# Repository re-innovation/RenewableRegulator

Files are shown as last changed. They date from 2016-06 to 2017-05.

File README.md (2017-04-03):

# Renewable Regulator

# Overview

This is an open-source project to design a simple, low-cost, Charge Regulator Designs for off-grid renewable energy projects.

A charge-controller protects a re-chargeable battery from over (and sometime under) charging from a renewable energy resource.

This controller will work as a Series and Shunt controller. Future improvements include working as a Maximum Power Point Tracking.
The design is based upon the Arduino IDE and will use one version of the Arduino processors (Arduino Nano initially).
Voltage is measured using a potential divider.
Current is measured using a hall-effect current sensor.
Temperature is measured using a 1-wire digital temperature probe.

A small OLED or LCD screen is used to show the data.
A rotary encoder is used for input data.
Data will also be sent via a serial connection for data-logging use.

## Specifications:

Maximum working voltage: 60V DC
Maximum working current: 50A DC
Measurement accuracy voltage:
Measurement accuracy current:
Temperature: -20 to 150C 0.1C steps

## Contributors

Overview and project concept by Matthew Little (matt@re-innovation.co.uk)
Phase 1 by Arnaud Moulas (arnaud.moulas@gmail.com)
Phase 2 by Yoan Gornes (yoan.gornes@gmail.com)

This project has been part of a larger project for modular power electronics concept initiated by Wind Empowerment:
http://www.wisions.net/projects/exchange-modular-power-to-the-people-democratising-energy-access-through-mo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

This section of the project is designed to stand-alone as a charge controller, but the code will be incorporated into the larger project.

# Series Regulator

A series charge controller or series regulator disables further current flow into batteries when they are full.

# Shunt Regulator

A shunt charge controller or shunt regulator diverts excess electricity to an auxiliary or "shunt" load, such as an electric water heater, when batteries are full.

# MPPT Algorithm

At present this function is not included. In the future a DC-DC converter can be used to separately

# Battery types

A rechargeable battery, storage battery, secondary cell, or accumulator is a type of electrical battery which can be charged, discharged into a load, and recharged many times, while a non-rechargeable or primary battery is supplied fully charged, and discarded once discharged. It is composed of one or more electrochemical cells. The term "accumulator" is used as it accumulates and stores energy through a reversible electrochemical reaction. Rechargeable batteries are produced in many different shapes and sizes, ranging from button cells to megawatt systems connected to stabilize an electrical distribution network.
Several different combinations of electrode materials and electrolytes are used, including lead–acid, nickel cadmium (NiCd), nickel metal hydride (NiMH), lithium ion (Li-ion), and lithium ion polymer (Li-ion polymer).

# Data Protocol

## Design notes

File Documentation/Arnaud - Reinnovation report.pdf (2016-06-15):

# CHARGE CONTROLLERS : SERIES, SHUNT, MPPT

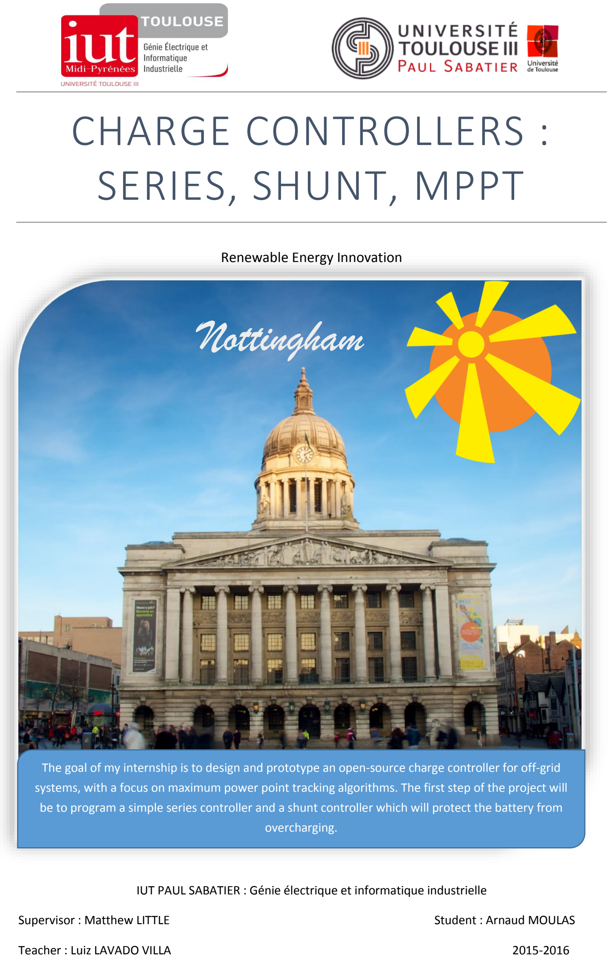
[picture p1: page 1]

Renewable Energy Innovation

# Nottingham

IUT PAUL SABATIER : Génie électrique et informatique industrielle

Supervisor : Matthew LITTLE | Student : Arnaud MOULAS
Teacher : Luiz LAVADO VILLA | 2015-2016

The goal of my internship is to design and prototype an open-source charge controller for off-grid systems, with a focus on maximum power point tracking algorithms. The first step of the project will be to program a simple series controller and a shunt controller which will protect the battery from overcharging.

Acknowledgement

2 | P a g e
Acknowledgement

# Acknowledgement

I would like to thanks :

- Lythisha who welcomed me to her house during the internship. She was really nice and she has a a cosy nice house near a supermarket and the tram. It allowed me to buy food for a cheap price and easily go to work thanks to the tram.
- Luiz Lavado Villa to put me in contact with Matthew little from the company Re-innovation.co.uk. Luiz was very active and really helpful. He organized meetings every weeks before the internship to prepare us. It permitted me to understand a bit prior to the internship the work I would have to do.
- Matthew Little who is my supervisor. He was attentive to me so it was a pleasure to work with him. He taught me a lot about how to lead a project from scratch. I am always surprised when I have a problem that Matthew can find the solution quickly.

Synopsis

Synopsis

# Synopsis :

Presentation of the company : | 4-5

Presentation of the company

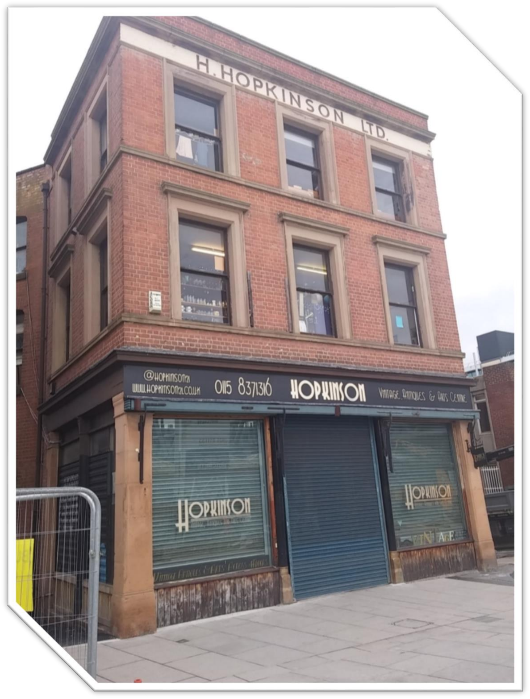
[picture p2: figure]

Presentation of the company

# Presentation of the company :

Re-innovation is a small business company created by Matthew little. It is mainly accessible for the customer through the website www.re-innovation.co.uk

Matthew’s workshop is at the second floor

Presentation of the company

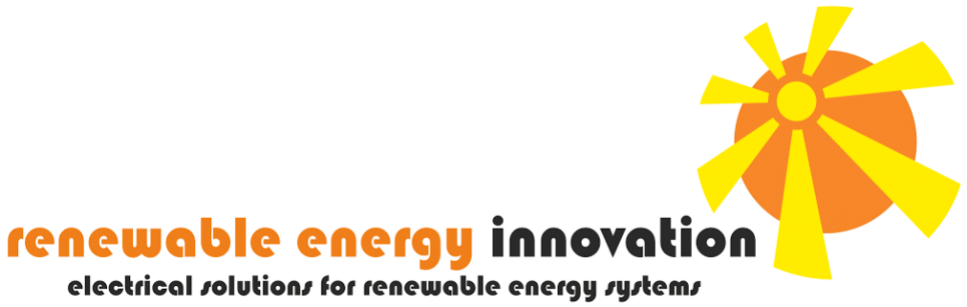
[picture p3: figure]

Presentation of the company

“Renewable Energy Innovation specialize in electrical and electronic systems for renewable energy projects, mainly solar, wind and micro-hydro. We focus on renewable energy based stand-alone power supply systems (off-grid systems). This includes power and energy monitoring, battery charge control and wiring systems. Projects we have been involved with range from small, portable solar-powered systems, through pedal powered devices up to large multi-kilowatt photovoltaic arrays. The projects, information and blog pages contain details of some of the projects we have worked on. We also design, build and test bespoke pieces of renewable energy equipment.” ~Matthew Little

I worked at the Hopkinson gallery which is a vintage shop and a coffee at the same time. Matthew’s workshop is on the second floor. I had a desk with all the equipment needed to program the arduino uno and test the algorithm. Matthew’s desk is in the next room so it is easy for me to communicate with him.

I have been working in really great condition.

Logo of the company

Introduction

Introduction

# Introduction :

I am a French student studying computer science. In order to get my degree I need to participate to an internship. Matthew Little responded positively to my mail and I am now happy to spend my internship in Nottingham for the company Re-innovation.co.uk. The plan for me was to design and test different charge controller’s algorithm on an arduino uno.

Initially the project was decomposed in 3 big parts :

Series controller :

1) Algorithm
2) Program on arduino
3) Test on the prototype

Shunt controller

1) Algorithm
2) Program on arduino
3) Test prototype

Maximum Power Point Tracking (MPPT) :

1) Algorithm
2) Program it on arduino
3) Test the prototype

However in practice the first 2 steps were merged as their functioning was similar.

Introduction

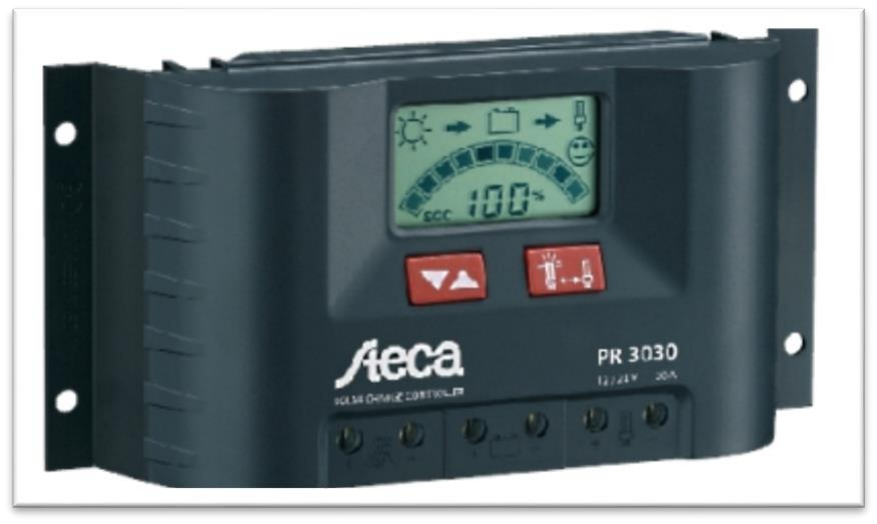
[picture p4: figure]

Introduction : Project

## Project :

The goal of my internship is to design and prototype an open-source charge controller for off-grid systems, with a focus on maximum power point tracking algorithms.

The first step of the project will be to program a simple series controller and a shunt controller which will protect the battery from overcharging.

Series controller : A series charge controller or series regulator disables further current flow into batteries when they are full.

Shunt controller : A shunt charge controller or shunt regulator diverts excess electricity to an auxiliary or "shunt" load, such as an electric water heater, when batteries are full

Before working Matthew explained me the project and detailed me each steps. He draw simple graphics it permit me to understand how is working the series controller from an electrical point of view.

Exemple of solar panel controller found in shops

Introduction

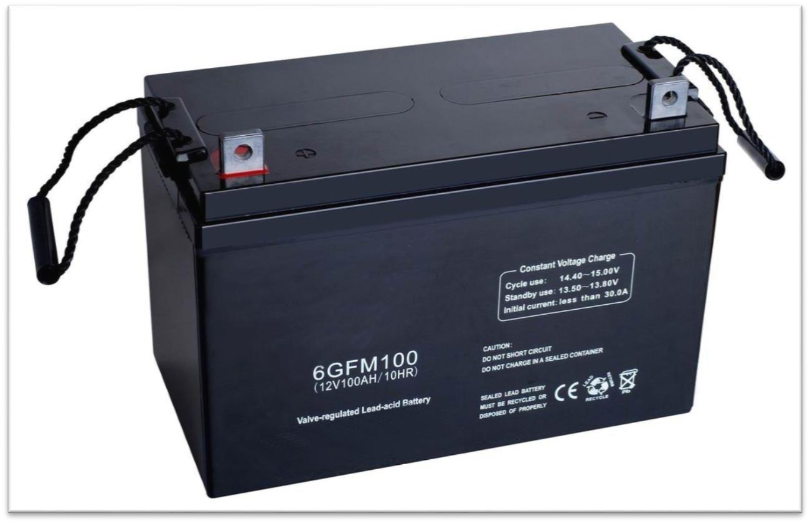
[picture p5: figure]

Introduction : What is a rechargeable battery ?

## What is a rechargeable battery :

A rechargeable battery, storage battery, secondary cell, or accumulator is a type of electrical battery which can be charged, discharged into a load, and recharged many times, while a non-rechargeable or primary battery is supplied fully charged, and discarded once discharged. It is composed of one or more electrochemical cells. The term "accumulator" is used as it accumulates and stores energy through a reversible electrochemical reaction. Rechargeable batteries are produced in many different shapes and sizes, ranging from button cells to megawatt systems connected to stabilize an electrical distribution network.

Several different combinations of electrode materials and electrolytes are used, including lead– acid, nickel cadmium (NiCd), nickel metal hydride (NiMH), lithium ion (Li-ion), and lithium ion polymer (Li-ion polymer). Rechargeable batteries initially cost more than disposable batteries, but have a much lower total cost of ownership and environmental impact, as they can be recharged inexpensively many times before they need replacing. Some rechargeable battery types are available in the same sizes and voltages as disposable types, and can be used interchangeably with them.

Usually the battery used with off grid energy are big and heavy

Introduction

Introduction : What are the cause of damage to a battery ?

## What are the cause of damage to a battery ?

## Damage from cell reversal

Subjecting a discharged cell to a current in the direction which tends to discharge it further to the point the positive and negative terminals switch polarity causes a condition called cell reversal. Generally, pushing current through a discharged cell in this way causes undesirable and irreversible chemical reactions to occur, resulting in permanent damage to the cell. Cell reversal can occur under a number of circumstances, the two most common being:

- When a battery or cell is connected to a charging circuit the wrong way around.
- When a battery made of several cells connected in series is deeply discharged.

In the latter case, the problem occurs due to the different cells in a battery having slightly different capacities. When one cell reaches discharge level ahead of the rest, the remaining cells will force the current through the discharged cell.

Many battery-operated devices have a low-voltage cutoff that prevents deep discharges from occurring that might cause cell reversal.

## Damage from overcharging

During the final stages of charging, all lead-acid batteries break down some of the electrolyte in a battery into hydrogen and oxygen. With sealed batteries, such as gel cells and AGMs, the gases are normally contained within the battery, although in certain circumstances (notably, persistent overcharging), enough internal pressure can build up to open pressure release valves and vent the gases. With wet cell batteries – the type that need topping up from time to time – the gases are always vented.

Hydrogen, which is highly explosive, is much lighter than air, so typically will rapidly rise and disperse, so long as there is even minimal venting from the top of a battery box and from the top of the compartment in which the battery box is housed. However, if a pocket of gas forms, any spark (such as from a brushed electric motor kicking on) may set off the hydrogen, on occasion resulting in a powerful explosion. This is what blew the top off the Fukushima nuclear power plants in Japan. Occasionally, internal short circuits create a spark inside batteries that can set off a hydrogen explosion within the battery, blowing the case open. Note that this can occur with sealed batteries as well as with wet cell batteries.

When batteries are worked hard, they generate a fair amount of internal heat. This increases a battery’s ability to absorb charging current without its voltage rising, which effectively disables any voltage regulator on the charging device, resulting in gross overcharging. The battery can get into a condition known as ‘thermal runaway’ in which it soaks up all the charging current that can be thrown at it, converting this into hydrogen, oxygen and heat – a dangerously potent mix. The only effective way to guard against this is to have temperature sensing at the battery, linked to the charging device.

Introduction

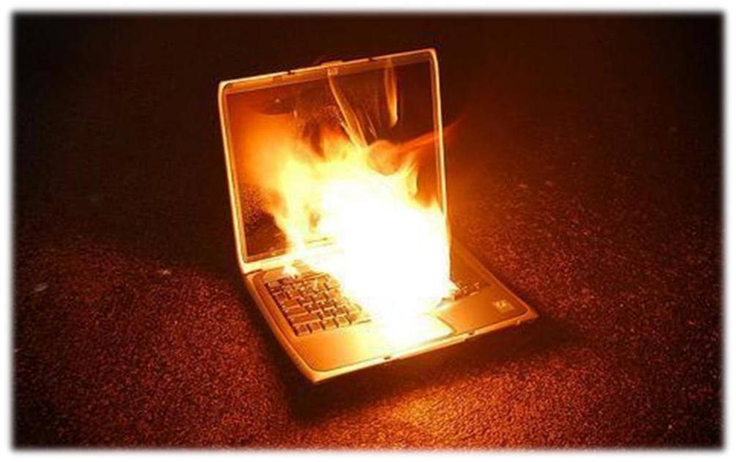
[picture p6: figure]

Introduction : What are the cause of damage to a battery ?

## Damage from over dis-charging

If a cell's voltage reaches a designed value, that means the battery has discharged the stored capacity, but still the discharge action is continual, over-discharge will cause. Commonly the end voltage can be identified through discharge current, for example the end voltage is set at 1.0V/cell as discharged at 0.2C-2C, and 0.8V/cell at 3C or more, e.g. 5C or 10C. Over discharge may cause disaster, especially at heavy current or repeated over discharge. Commonly over discharge can make cell inner pressure raise, and the reversibility of activity materials both in positive and negative will be damaged. Even by charge only part can recover and the capacity is reduced obviously.

A laptop’s battery can burn if too much damaged

Introduction

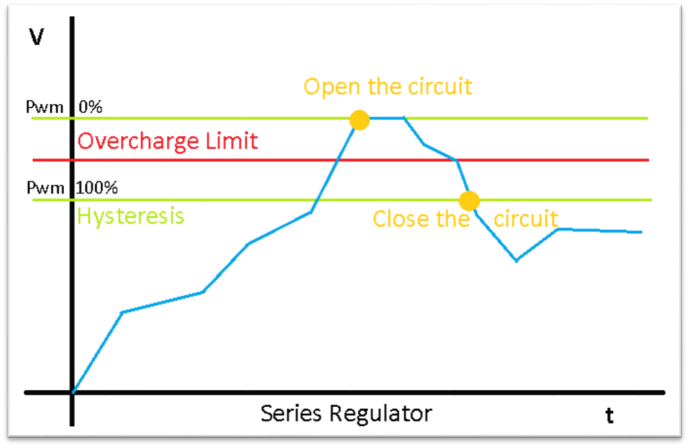
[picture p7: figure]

Introduction : Different type of charge controllers

## Different type of charge controllers :

## Series controller :

Electric scheme for serie controller

The series controller works by providing a path from the supply voltage to the load through a variable resistance (the main transistor is in the "top half" of the voltage divider). The power dissipated by the regulating device is equal to the power supply output current times the voltage drop in the regulating device.

Series controller can only be used for current limited power sources (such as solar panels).

Illustration of the behavior of Series controller

Introduction

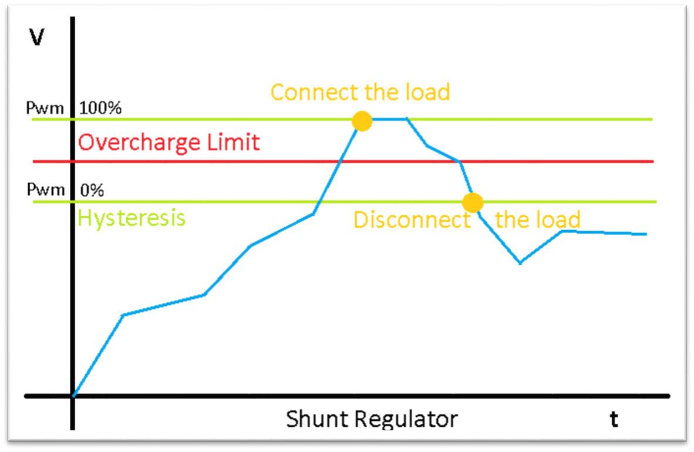
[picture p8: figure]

Introduction : Different type of charge controllers

## Shunt controller :

Electric scheme for Shunt controller

The shunt controller works by providing a path from the supply voltage to ground through a variable resistance (the main transistor is in the "bottom half" of the voltage divider). The current through the shunt controller is diverted away from the load and flows uselessly to ground, making this form usually less efficient than the series controller. It is, however, simpler, sometimes consisting of just a voltage-reference diode, and is used in very low-powered circuits where the wasted current is too small to be of concern. This form is very common for voltage reference circuits. A shunt controller can usually only sink (absorb) current.

Series controller can be used for Solar, Wind and Hydro.

Illustration of the behavior of Shunt controller

Introduction

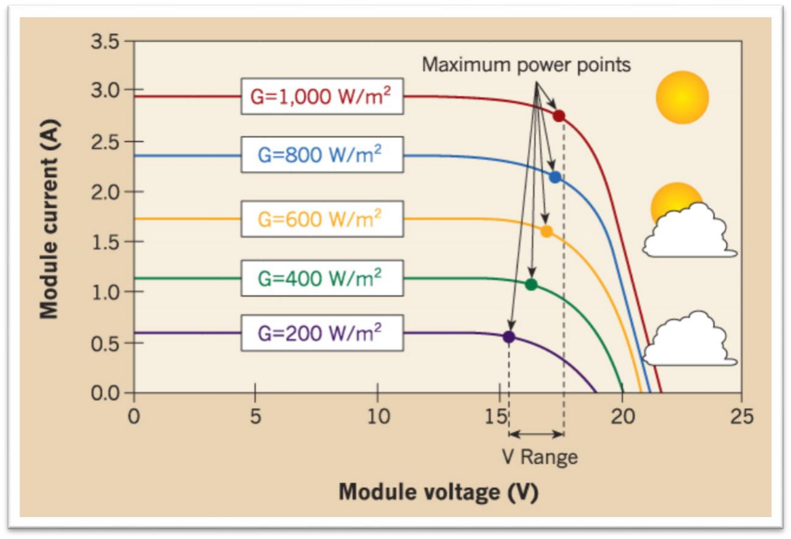
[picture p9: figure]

Introduction : Different type of charge controllers

## Maximum Power Point Tracking ( MPPT ) :

Maximum power point tracking (MPPT) is a technique used with wind turbines and photovoltaic (PV) solar systems to maximize power output.

The central problem addressed by MPPT is that the efficiency of power transfer from the solar cell depends on both the amount of sunlight falling on the solar panels and the electrical characteristics of the load. As the amount of sunlight varies, the load characteristic that givesthe highest power transfer efficiency changes, so that the efficiency of the system is optimized when the load characteristic changes to keep the power transfer at highest efficiency. This load characteristic is called the maximum power point and MPPT is the process of finding this point and keeping the load characteristic there. Electrical circuits can be designed to present arbitrary loads to the photovoltaic cells and then convert the voltage, current, or frequency to suit other devices or systems, and MPPT solves the problem of choosing the best load to be presented to the cells in order to get the most usable power out.

Illustration of the behavior of a MPPT controller

Presentation of my work

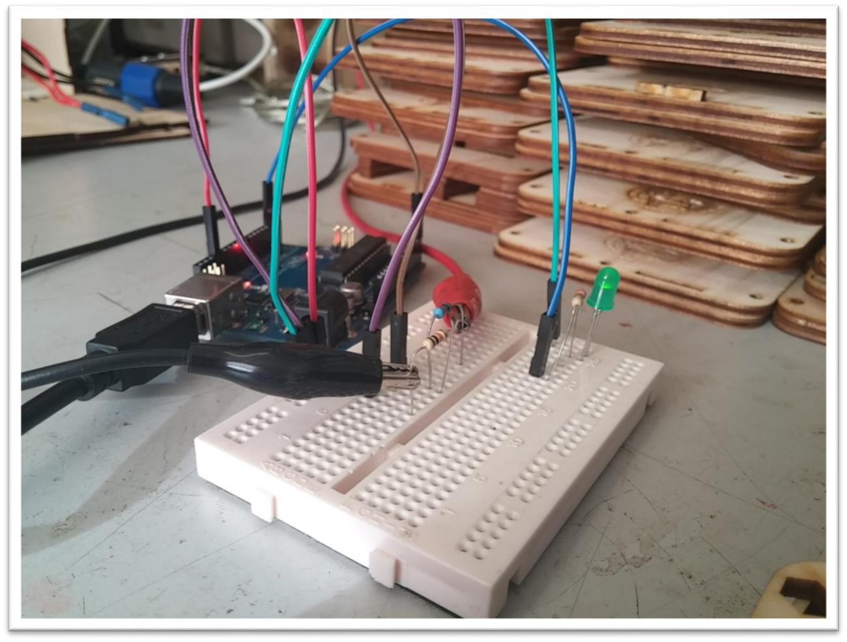
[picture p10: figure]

Presentation of my work : test board

# Presentation of my work

## Preparation of the test board :

During the first week I did some research to understand the functioning of charge controllers (series, shunt, MPPT). The goal of my first program was to simulate the behavior of the series controller on the serial output. I programmed the arduino in order to process the input measured voltage. It will write “light on” or “light off” depending on the state of the battery. (overcharged or not)

Once this was working Matthew proposed to test it by using a prototype board with a led. The led will represent the state of the mosfet. (open = light on , close = light off)

The white piece of plastic is the prototype area. It is used to easily connect different component.

Test on the prototype :Processing the voltage input to determine the state of the led

Presentation of my work

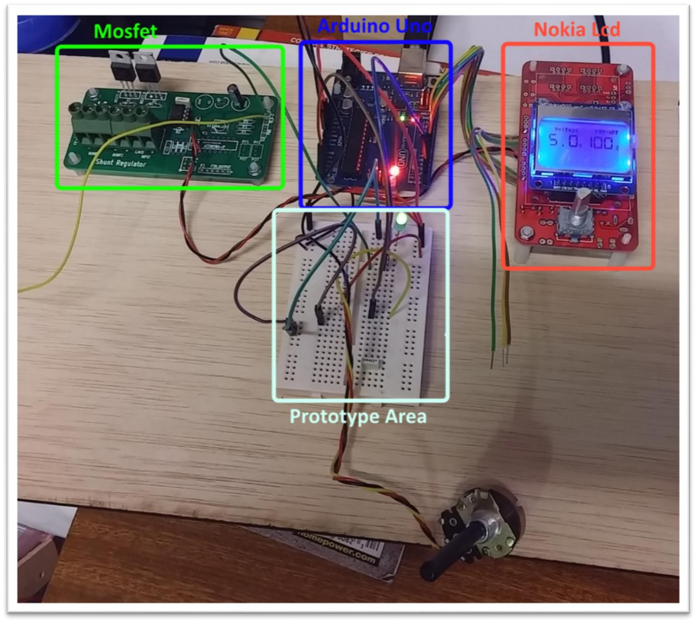
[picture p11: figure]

Presentation of my work : complete prototype

Currently I am measuring the voltage after the potential divider on the analogue Input of the arduino. I can change the voltage thanks to a power supply and if the voltage is higher than the security limit of the battery I will light the light off the led.

I took some time to learn how to convert the analogue value in voltage (I used the sensibility in voltage of the arduino to convert the value from analogue to volt) and I needed some time to get used programming the arduino in C.

## First contact with the fully functional prototype of series/shunt controller

Matthew built me a prototype of series / shunt controller with a board of wood, and arduino, a nokia LCD, a LED and some other electrical component.

here is the prototype with the lcd working, it’s a bit ahead of what I programmed at the moment

Presentation of my work

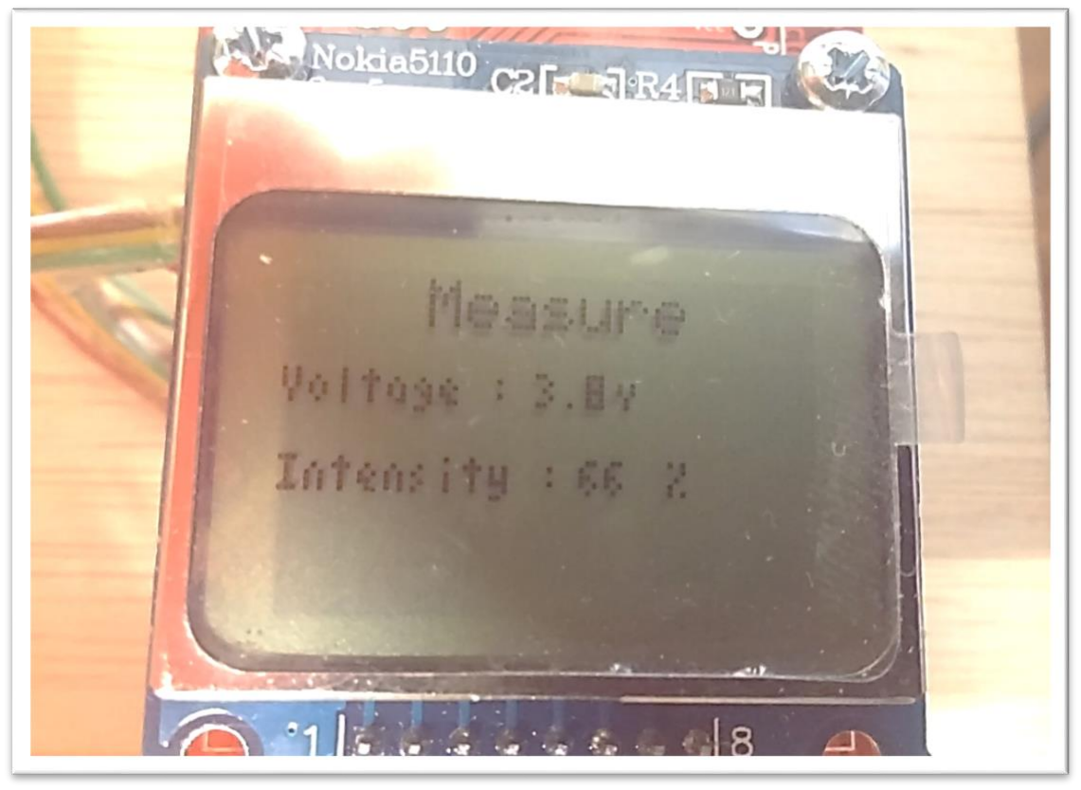
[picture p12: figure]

Presentation of my work : finished display

I was surprised by the quality of the prototype he screw the electronic board on the wooden board. Thanks to it’s robust structure I could bring the prototype home without doubts.

- The green board is the mosfet part.
- The blue board is the arduino uno which will control all component in function of the measured voltage.
- The white one is used to easily connect or remove component
- The red one was designed to be for GPS use but Matthew only connected the nokia lcd and a digital encoder (button)

It took me some time to understand how to use the different components. In particular the Nokia LCD and the digital rotary encoder. After some research I decided to use an online library to control the lcd. I tested the different libraries to find the easiest one to use and which provide a lot of function.

My first display was this one :

First grip on the use of library and nokia LCD

It was very basic but I managed to get the value actualized in real time. It was good enough to test my series / shunt controller at the moment.

Presentation of my work

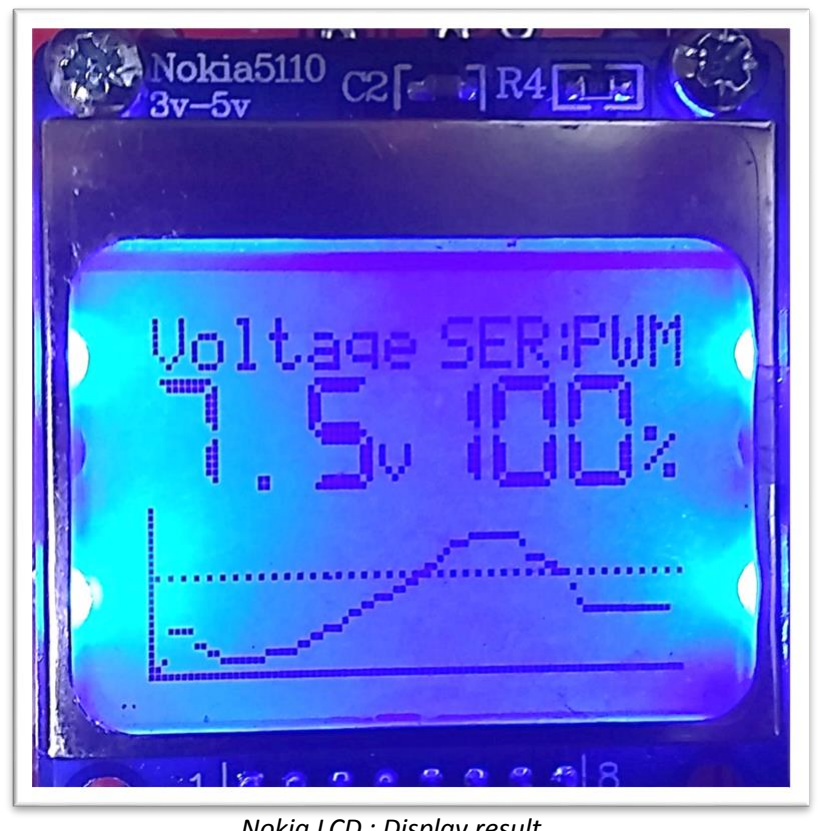
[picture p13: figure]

Presentation of my work : complete prototype

The next step was designing four different functions which will be used to control the PWM. It means the led will light according to the quantity of current. (the led is a representation of the current the controller let pass) Here are the four functions :

- Series controller
- Series controller with pwm
- Shunt controller
- Shunt controller with pwm

## Implementation of the algorithm on the prototype board

I started to control the arduino with more advanced function. I used the function “map” in order to interpret the voltage value. These values are then used to draw a graphic on the screen which represent the voltage value over time. Thanks to the map function it is compatible with every voltage range. However under 22 volt of range it will not draw a nice curve because there is 22 dot on the y axis. If there is less than 1 volt per dot it will still draw the point put the curve will look like a “stair”.

Then my work got focused to control the digital rotary encoder in order to switch between the different control mode. When you turn the digital encoder to the right every five click it will switch to next mode.

Another little function I added is the Sleepmode for the lcd. However it was not really interesting the way I controlled it in the first place. (because it was in confrontation with the normal use of the controller) so I kept it as a draft and will implement it later.

Nokia LCD : Display result

Presentation of my work

Presentation of my work : difficulties

## Program the board for easy control

The main goal was to make accessible the interface. I had to think how to facilitate the user’s utilization of the prototype. The prototype had only one button which is a digital rotary encoder. In order to realize this I deplaced the sleep function of the lcd. From now when the button is pushed it will enter the menu.

In the menu, the user will be able to change every parameter in order to adapt the charge controller to his battery. It will be possible to activate the sleep mode in the menu.

The biggest difficulty I encountered was the lack of memory (ram). I had to use the eprom and store in it the all the text (print).

After that Matthew told me to store the values in the eprom to prevent the loss of the information if there is a reset. Once I did it, I got some difficulty to read the value. I add to find ‘complex’ arduino function on the internet ( they were not written explicitly on the arduino website but they are in the base arduino library).

At this point the program and the prototype looks like a finished product.

## Major difficulties for the Series and Shunt controller program :

- Convert the theory of a charge controller into a program
- Initialize and use the different components (lcd, digital encoder)
- Need to free memory (ram)
- Write and read the eprom correctly
- Adapt the prototype to the user utilization

Presentation of my work

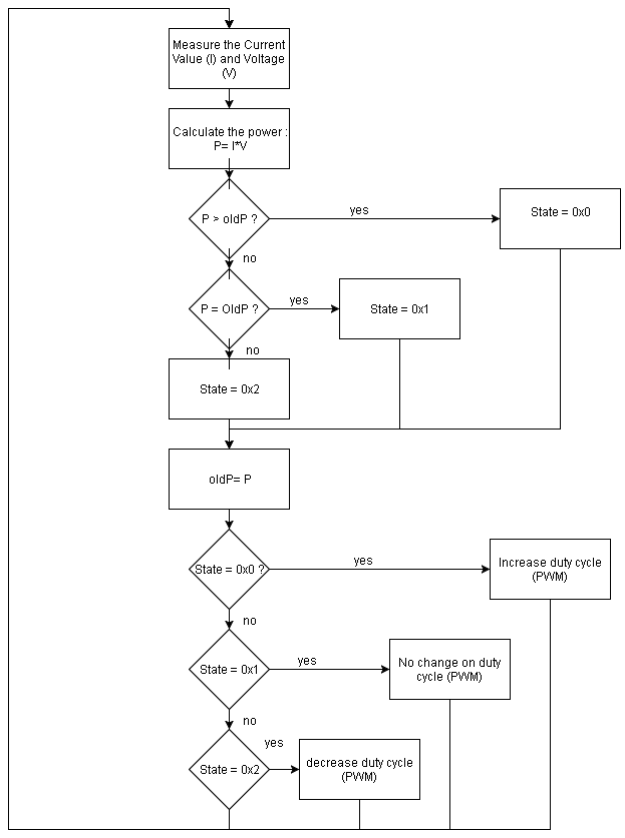
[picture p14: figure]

Presentation of my work : first MPPT algorithm

## Algorithm and first program of an MPPT

Presentation of my work

Presentation of my work : first MPPT algorithm

I started to work on the MPPT. The initial step was to understand the theory behind an MPPT. There was multiple methods to design one. Matthew gave a lot of good thesis or documents to find information about differents MPPT. We choose the “hill climbing method” because it’s easy to understand.

At this point Matthew was thinking how to improve the prototype in order to allow me to test my program on it.

I designed a first algorithm which I sent to Yoann (another student from GEII which is in Peru ! ) in order to share our work on the subject . Here is my first design (on the previous page)

This design has many flaw but I did not realized it before testing it on the prototype.

During the first testing I though the algorithm was working as intended because of the model of power supply I was using always deliver the highest current. Basically my algorithm was just increasing the value of the pwm.

However the behavior of a solar panel is completely different. I will detail this problem a bit later.

Presentation of my work

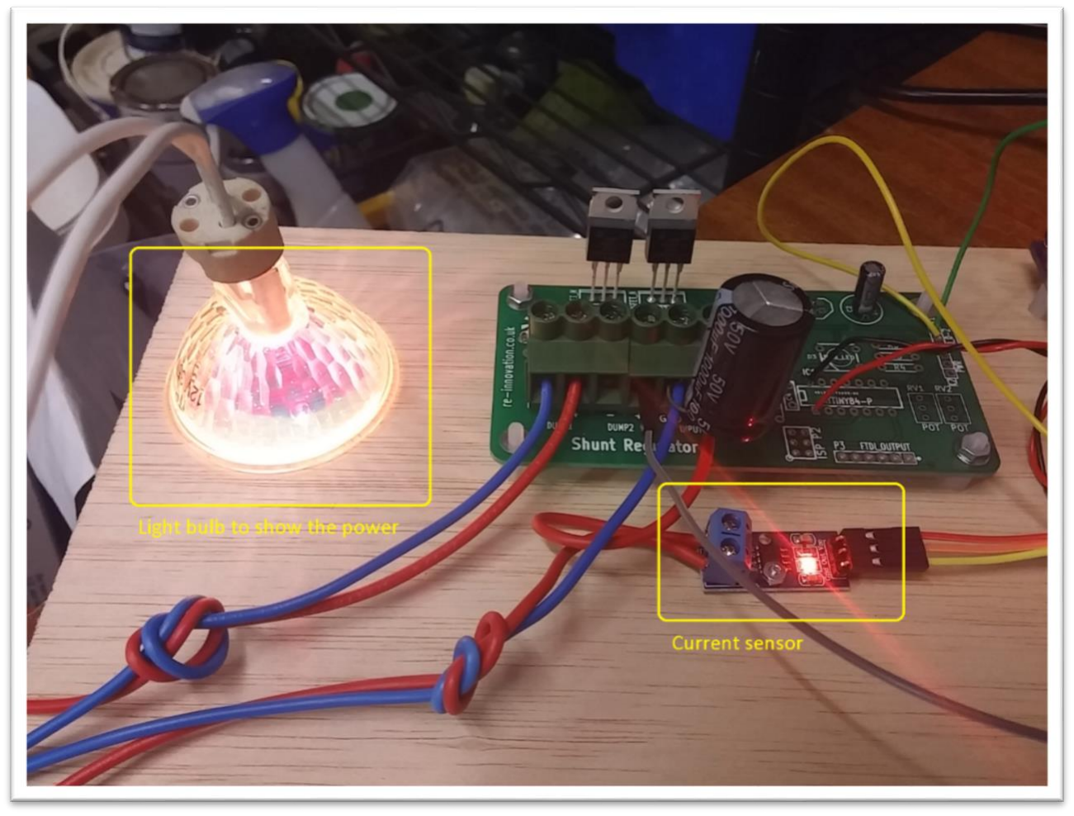
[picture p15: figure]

Presentation of my work : prototype board for the MPPT algorithm

## Prototype board upgraded to support an MPPT algorithm:

Matthew adapted the prototype to work with an MPPT program. As you can see on the picture he added a current sensor (which is used to convert the current into a voltage which is read on the arduino analog input)

However we got a problem of electricity noise. It damaged the nearest electronics. Matthew fixed this problems by forming an inductor with the cable and adding a capacitor on the input voltage from the power supply. At first I thought my program was working as intended because this power supply will always deliver enough current to reach the higher power.

The maximum power point I was looking for was moving on a linear line. When we then proceeded to test the prototype whit Matthew Power Supply (it is possible to limit the current on this one) We saw that my program reached its limit : it got further than the MPPT.

I also did a scan function which will only execute itself 1 times at the startup. It will measure the power for each values of the pwm (0 – 255) and then save the pwm’s value with the higher power. It will start the main program at the MPPT and then the main program (in the arduino’s loop) will track the maximum power point according to the variations.

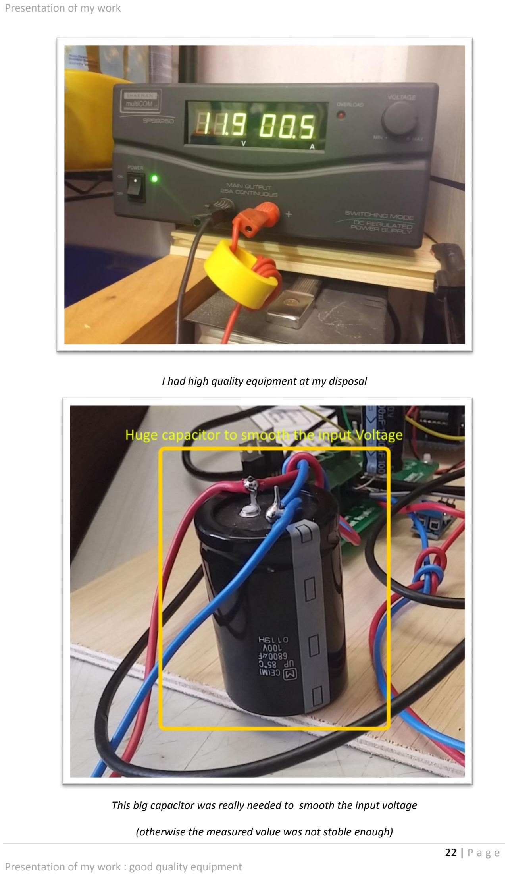
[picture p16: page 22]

Presentation of my work

Presentation of my work : good quality equipment

I had high quality equipment at my disposal

This big capacitor was really needed to smooth the input voltage

(otherwise the measured value was not stable enough)

Presentation of my work

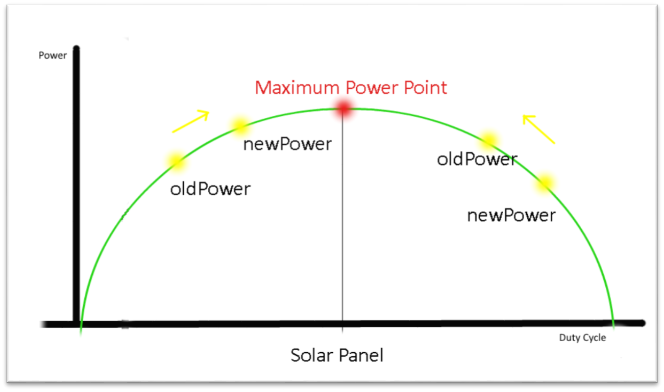
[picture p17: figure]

Presentation of my work : difficulties with the MPPT

## Difficulties for the MPPT algortihm :

- Wrong tracking when going the other side of the curve.

On my first try to design an algorithm I was using a power supply which has no limitation on the current. It always deliver the most current to reach the highest output possible. The result was that I designed an algorithm to climb a straight line. When I tested with Matthew the algorithm on a power supply with limitation of current the algorithm could not track the maximum power point. Indeed it was lost on the right side of the curve.

Illustration to show the need to adapt the algorithm to the side of the curse

Presentation of my work

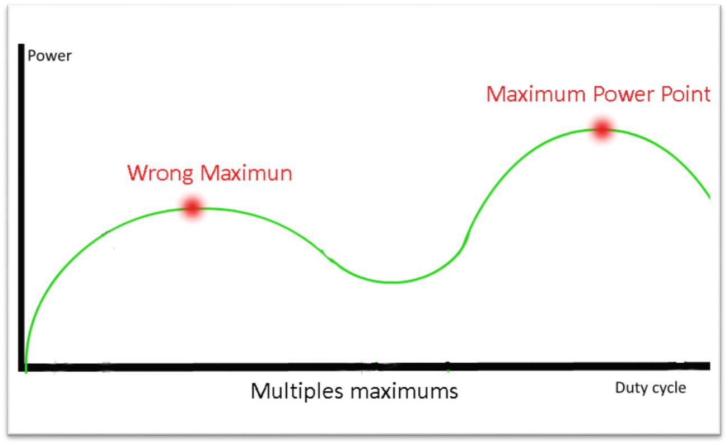
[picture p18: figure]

Presentation of my work : difficulties with the pwm algorithm

- Second MPPT problem : Multiple Maximum

Once the MPPT algorithm fixed there was another problem. While the tracking of the maximum power point was working there was the problem of being stuck on a small value (See below). I designed a scanning function which will execute itself every 10 min in order to find the highest point. It will prevent the algorithm of being stuck on a small pike.

Illustration to show the risk of being stuck at a wrong maximum

The next improvement will be to create a function which will adapt the variation of the pwm value to improve the speed of the tracking. It will need to decrease to the minimal variation of the pwm ( +1/-1) once it’s near the MPPT. (To prevent from going to much farther of it)

Algorithm

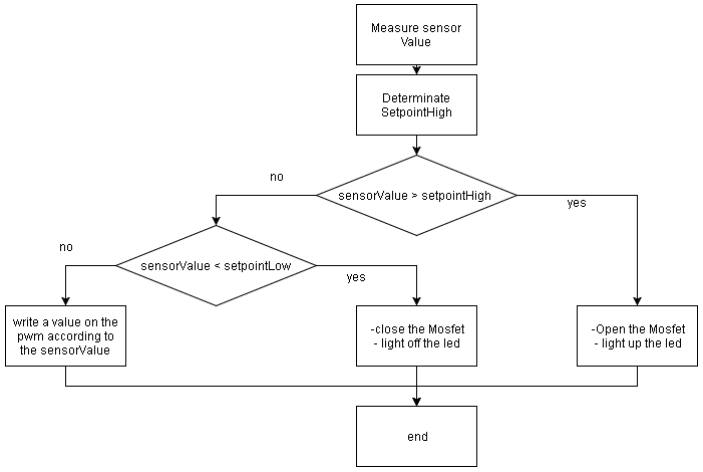
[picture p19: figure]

Algorithm : Series controller

# Algorithm:

## Series algortihm :

Series Algorithm

Algorithm

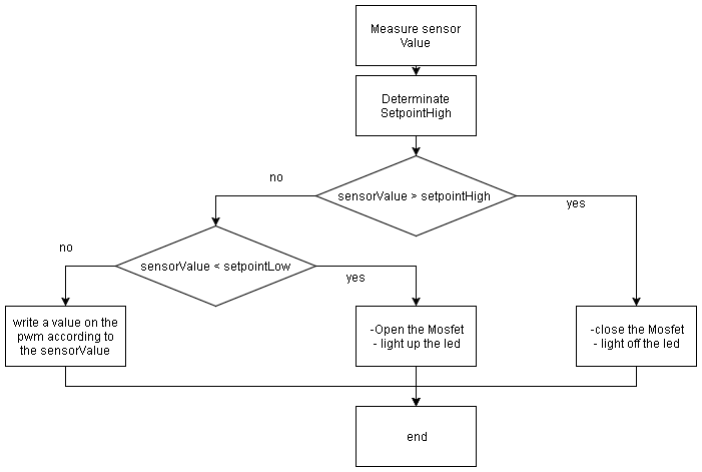
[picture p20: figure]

Algorithm : Shunt controller

## Shunt algortithm :

Shunt Algoritm

Algorithm

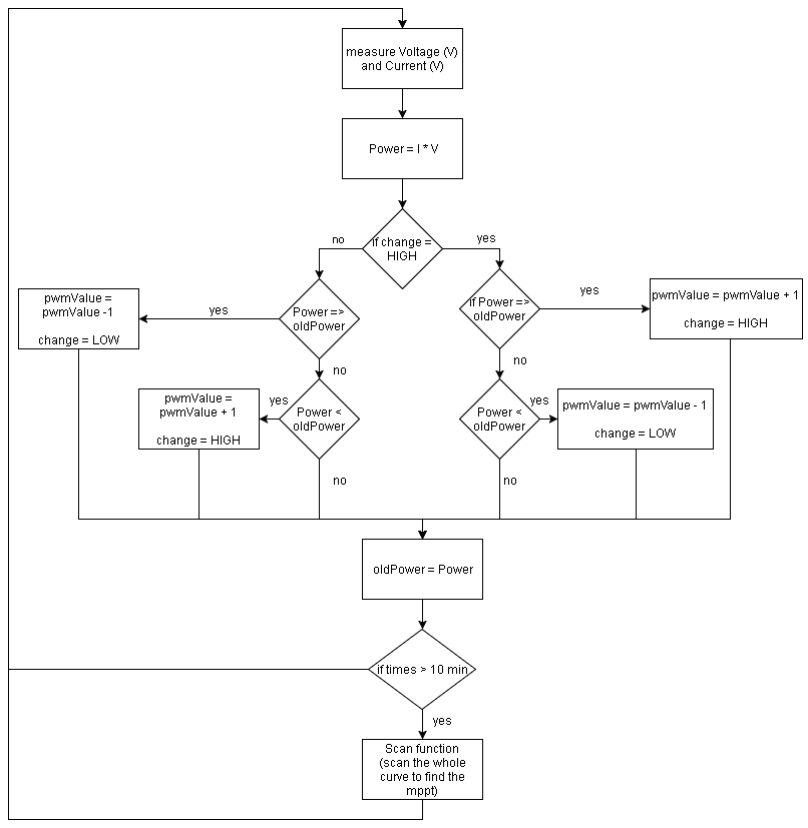
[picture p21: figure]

Algorithm : MPPT controller

## Mppt algorithm :

MPPT algorithm

Algorithm

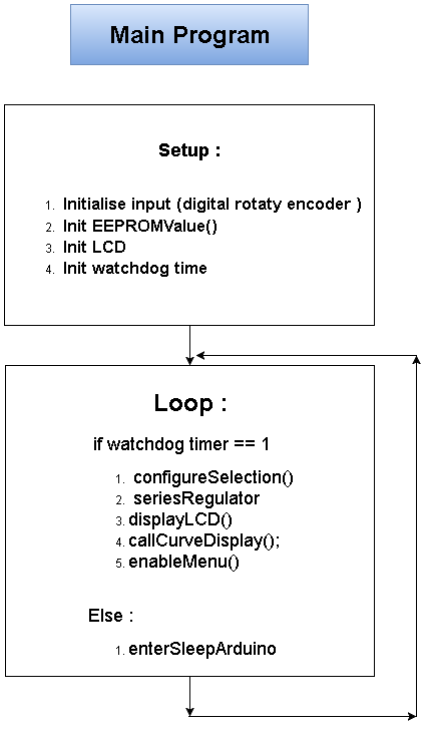
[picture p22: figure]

Algorithm : Series / Shunt arduino program

## Series/Shunt Arduino program :

Arduino program of the Series / Shunt controller

Algorithm

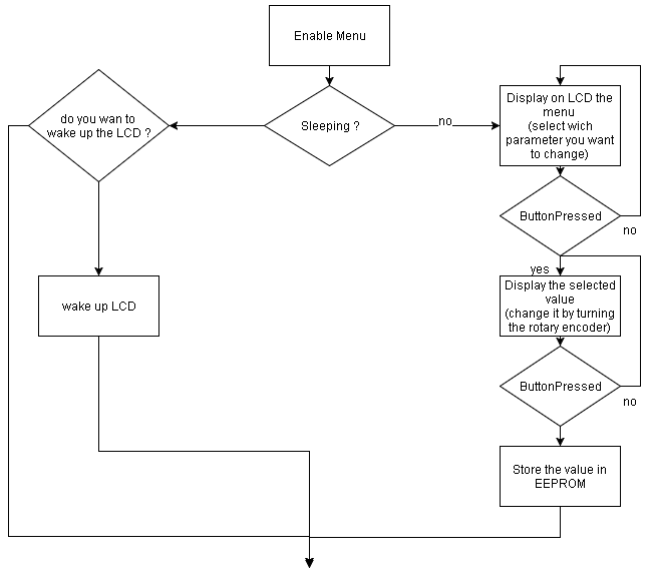
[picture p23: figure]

Algorithm : Enable menu

## Enable menu algorithm :

Algorithm of the function “Enable menu” in the arduino program

Outcome of my internship

Outcome of my internship

# Outcome of my internship :

## For Re-innovation.co.uk

I designed and implemented a series and shunt controller program. I believe this program is well finished because I had the time to test it with Matthew. We corrected several little problem which would occur for a normal user.

It is possible to sell kit for people who want a customizable Series / Shunt controller.

## For me :

I learned a lot at the side of Matthew. He is a very dynamic person and is always listening to me. I learned how to lead a project from scratch. That means starting with a design on paper to a fully functional prototype.

It developed the skills I learned from my formation GE2I (in both electronic and programming).

Furthermore on the personal side it confirmed me that I would like to pursue with engineer study especially in the domain of programming.

Nottingham is a nice city, it is near London and Birmingham so it is easy and cheap to do sightseeing. It’s a smaller than Toulouse but the architecture of the city center is way more contemporary than Toulouse one. There is a more three and public garden too. I really liked doing my jogging around the city.

I really liked to work with the Luiz’s association, it is a pleasure to share my work with Yoann Rey. I really feel the impression to be part of a bigger project.

Bibliography / Annexes

Bibliography / Annexes

# Bibliography

- Wikipedia : Theory behind the Series , Shunt , MPPT controller
- Matthew’s book “Engineering in development Energy” : Theory about Series / Shunt / MPPT
- Batteryspace.com : Information about the batteries (like causes of the damage to a battery)
- MPPT algorithm : Thesis from Esram IEEE 2007 “Hill climbing method”

# Annexes

Code in C for arduino Uno :

(most important functions)

- Annexe 1 : DrawBatteryLimit
- Annexe 2 : DrawCurve
- Annexe 3 : PinA
- Annexe 4 : PinB
- Annexe 5 : MPPT Algorithm
- Annexe 6 : Series Algorithm
- Annexe 7 : Shunt Algorithm

Annexes

# ANNEXES

Code in C for arduino Uno :

(most important functions)

- | Annexe 1 : drawBatteryLimit | – Draw the overcharge limit on the nokia lcd
- | Annexe 2 : drawCurve | _ Draw the evolution of the input voltage overtime and display it on the nokia LCD.
- | Annexe 3 : PinA | _ Used to detect the rotation of the digital rotary encoder
- | Annexe 4 : PinB | _ Used to detect the rotation of the digital rotary encoder
- | Annexe 5 : MPPT algorithm | _ Code of the MPPT algorithm
- | Annexe 6 : ControlSeriePWM | _ Code of the Series controller with PWM
- | Annexe 7 : ControlShuntPWM | _ Code of the Shunt controller with PWM

drawBatteryLimit | drawCurve
2 | P a g e
Annexes

## Annexe 1 : drawBatteryLimit

void drawBatteryLimit(void)

{ float mappedVinMax;

char positionX;

bool test =0;

mappedVinMax=map(VinMax,0,maxControllerVoltage, 0, 22);

for (positionX=1; positionX <= 83; positionX++)

{

myGLCD.setPixel(positionX,(46-mappedVinMax));

if(test==0)

{

test=1;

}

else

{

myGLCD.invPixel(positionX, (46-mappedVinMax));

test=0;

}

}

}

# Annexe 2 : drawCurve

void drawCurve(byte numberArray)

{ float mappedValueVin;

byte testNumberArray;

mappedValueVin=map(Vin,0,maxControllerVoltage, 0, 22);

arrayVin[numberArray]= mappedValueVin;

for (testNumberArray=1; testNumberArray <= numberArray; testNumberArray++)

{

myGLCD.setPixel(testNumberArray,(46-arrayVin[testNumberArray]));

}

}

PinA | PinB
3 | P a g e
Annexes

# Annexe 3 : PinA

void PinA(){

cli(); //stop interrupts happening before we read pin values

reading = PIND & 0xC; // read all eight pin values then strip away all but pinA and pinB's values

if(reading == B00001100 && aFlag) { //check that we have both pins at detent (HIGH) and that we are expecting detent on this pin's rising edge

encoderPos --; //decrement the encoder's position count

bFlag = 0; //reset flags for the next turn

aFlag = 0; //reset flags for the next turn

}

else if (reading == B00000100) bFlag = 1; //signal that we're expecting pinB to signal the transition to detent from free rotation

sei(); //restart interrupts

}

# Annexe 4 : PinB

void PinB(){

cli(); //stop interrupts happening before we read pin values

reading = PIND & 0xC; //read all eight pin values then strip away all but pinA and pinB's values

if (reading == B00001100 && bFlag) { //check that we have both pins at detent (HIGH) and that we are expecting detent on this pin's rising edge

encoderPos ++; //increment the encoder's position count

bFlag = 0; //reset flags for the next turn

aFlag = 0; //reset flags for the next turn

}

else if (reading == B00001000) aFlag = 1; //signal that we're expecting pinA to signal the transition to detent from free rotation

sei(); //restart interrupts

MPPT algorithm | MPPT algorithm
4 | P a g e
Annexes

# Annexe 5 : MPPT algorithm

if (change == HIGH ) | //algorithm of the mppt

{

if (newPower >= oldPower)

{

pwmValue = pwmValue + (int)pwmVariation;

change = HIGH;

}

else if (newPower < oldPower)

{

pwmValue = pwmValue - (int)pwmVariation;

change = LOW;

}

}

else if (change == LOW)

{

if(newPower >= oldPower)

{

pwmValue = pwmValue - (int)pwmVariation;

change = LOW;

}

else if (newPower < oldPower)

{

pwmValue = pwmValue + (int)pwmVariation;

change = HIGH;

}

}

if (pwmValue >= 255) | //Prevent the pwmValue to go higher
than its limit

{

pwmValue = 255;

}

else if (pwmValue <= 0) | //Prevent the pwmValue to go lower
than its limit

{

pwmValue = 0;

}

oldPower = newPower; | // save the newPower as the oldPower

analogWrite(5, (pwmValue));

Series algorithm | Shunt algorithm
5 | P a g e
Annexes

# Annexe 6 : controlSeriePWM

void controlSeriePWM(void)

{

if(verificationSetpointHigh(sensorValue,setpointHigh)==1) //Voltage higher than setpointHigh

{

digitalWrite(overchargeIndicatorLed, LOW); // Light up the led

}

else if (verificationSetpointLow(sensorValue,setpointLow)==1)

{

digitalWrite(overchargeIndicatorLed, HIGH); // Light off the led

}

else

{

PWMwrite (sensorValue, overchargeIndicatorLed);

}

}

# Annexe 7 : controlShuntPWM

void controlShuntPWM(void)

{

if(verificationSetpointHigh(sensorValue,setpointHigh)==1) //Voltage higher than setpointHigh

{

digitalWrite(overchargeIndicatorLed, HIGH); // Light up the led

}

else if (verificationSetpointLow(sensorValue,setpointLow)==1)

{

digitalWrite(overchargeIndicatorLed, LOW); // Light off the led

}

else

{

PWMwriteShunt(sensorValue, overchargeIndicatorLed);

}

}

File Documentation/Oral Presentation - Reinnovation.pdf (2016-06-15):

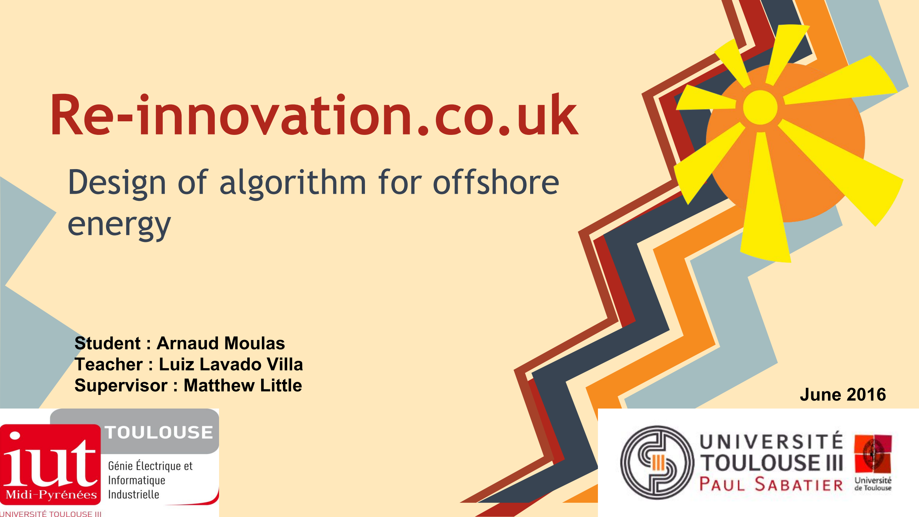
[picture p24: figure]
Re-innovation.co.uk; Design of algorithm for offshore energy; Student : Arnaud Moulas Teacher : Luiz Lavado Villa; Supervisor : Matthew Little; June 2016

Introduction : Nottingham


Re-innovation.co.uk

Project

● The goal of my internship is to design and prototype an open-
source charge controller for off-grid systems, with a focus on
maximum power point tracking algorithms.

Algorithm; Program on arduino; Test on the prototype; ● Translate in C; ● Control the memory space; ● Verify with Matthew

Designing and testing method

● Test the
behavior of the
controller

● Use library to
control the
other
component

Theory : Series controller


- Low price
- Can only be
used with
solar panel

Theory : Shunt controller

- Low price
- Lose of
current
- Can be used
with every
energy (solar,
wind and
hydro)


Theory :Maximum Power Point Tracking


- Maximum output
at any time
- Higher price
- Can be used
with every type
of energy


MPPT : Hill climbing method


MPPT : Hill climbing method

Algorithm : Series Controller


Algorithm : Shunt Controller


Algorithm :
MPPT
Right side of the curve | Left side of the curve


Good equipement

- Power supply
- Prototype board
- Oscilloscope


My work :

Prototype | LCD : Display of the result and the curve


My work :

Nokia LCD : Display result | Nokia LCD : Menu | 16


Mppt prototype :

Biggest technical difficulties :

- Use of all the component
- Nokia Lcd
- Rotary Digital Encoder
- Interrupt
- Manage the memory
- Use of the EEPROM
- Test of the MPPT algorithm

Outcome for the company :

- Series / shunt control finished
- Mppt algorithm working
- Possibility to sell kit of series / shunt controller.


Logo of the company

Outcome for me :

- C programation
- Library
- EPROM
- Project
- Design
- Test method
- prototype
- First professional
experience in the
electronic domain
- First insertion in a foreign country
- Team work with other
student from GE2i
(Yoann Rey )
Skill progress : | Self enrichment :


Questions

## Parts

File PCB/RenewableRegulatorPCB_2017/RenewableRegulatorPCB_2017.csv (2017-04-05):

Reference | Value | Footprint | Datasheet | Description | Manufacturer | Manufacturer Part No | Supplier 1 | Supplier 1 Part No | Supplier 1 Cost | Supplier 2
C1 | 100nf | matts_components:C1_wide_lg_pad |  |  |  |  |  |  | £0.05
C2 | 100nf | matts_components:C1_wide_lg_pad |  |  |  |  |  |  | £0.05
C3 | 100uf | REInnovationFootprint:C_1V7_TH |  | 100V Electrolytic | Panasonic | ECA-2AM101B | RS | 807-3431 | £0.14
C4 | 100nf | matts_components:C1_wide_lg_pad |  |  |  |  |  |  | £0.05
C5 | 100nf | matts_components:C1_wide_lg_pad |  |  |  |  |  |  | £0.05
C6 | 2.2uf | REInnovationFootprint:C_1V7_TH | http://docs-europe.electrocomponents.com/webdocs/156e/0900766b8156ecdd.pdf | 60V+ Ceramic Low ESR | Murata | RDEC72A225K3M1H03A | RS | 133-5714 | £0.79
C7 | 1uf | REInnovationFootprint:C_1V7_TH |  | >25V Electrolytic/Ceramic | Murata | RCER71H105K2M1H03A | RS | 841-0755 | £0.28
C8 | 100nf | matts_components:C1_wide_lg_pad |  |  |  |  |  |  | £0.05
C9 | 1uf | REInnovationFootprint:C_1V7_TH |  | >25V Electrolytic/Ceramic | Murata | RCER71H105K2M1H03A | RS | 841-0755 | £0.28
C10 | 10uf | REInnovationFootprint:C_1V7_TH |  | Low ESR. 25V | Panasonic | EEUFR1H100 | RS | 923-2745 | £0.05
D1 | 3v3 | REInnovationFootprint:TH_Diode_1 |  |  |  |  |  |  | £0.07
D2 | 3v3 | REInnovationFootprint:TH_Diode_1 |  |  |  |  |  |  | £0.07
D3 | 1N5819 | REInnovationFootprint:TH_Diode_1 | https://www.diodes.com/assets/Datasheets/ds23001.pdf | 1A Schottky Diode | Diodes Inc | 1N5819 | AliExpress |  | £0.07
D4 | 1N5819 | REInnovationFootprint:TH_Diode_1 | https://www.diodes.com/assets/Datasheets/ds23001.pdf | 1A Schottky Diode | Diodes Inc | 1N5819 | AliExpress |  | £0.07
D5 | WS2811_5mm | REInnovationFootprint:TH_WS2811_LED_8mm | https://www.coolcomponents.co.uk/en/opto/leds/digital-rgb-addressable-led-5mm-through-hole-10-pack.html | TH WS2811 Single LED Addressable |  |  | AliExpress |  | £0.50
D6 | 1N5822 | REInnovationFootprint:TH_Diode_1 | http://docs-europe.electrocomponents.com/webdocs/14bb/0900766b814bbef7.pdf | Schottky Diode >1A | HY Electronic Corp | 1N5822 | RS | 917-9102 | £0.05
D7 | LED | REInnovationFootprint:TH_LED-5MM_larg_pad |  |  |  |  |  |  | £0.10
D8 | UF4002 | REInnovationFootprint:TH_Diode_1 | http://docs-europe.electrocomponents.com/webdocs/12cf/0900766b812cffe7.pdf | Fast rectifier for Flyback. 100V | Vishay | UF4002-E3 | RS | 628-9732 | £0.12
D9 | 1N5819 | REInnovationFootprint:TH_Diode_1 | https://www.diodes.com/assets/Datasheets/ds23001.pdf | 1A 0.850V Schottky 1A | Diodes Inc | 1N5819 | Aliexpress |  | £0.07
DISP1 | OLED_I2C | REInnovationFootprint:TH_OLED1306 |  |  |  |  |  |  | £4.00
DISP2 | SPI_LCD | REInnovationFootprint:TH_LCD_SPI_128x128 | https://www.elecrow.com/wiki/index.php?title=1.44%27%27_128x_128_TFT_LCD_with_SPI_Interface | An SPI Colour LCD with backlight | Elecrow
EN1 | ENCLOSURE |  | http://cpc.farnell.com/hammond/1590bb/box-diecast-119x94x30/dp/EN82042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 | Enclosure for unit
ENC1 | Encoder | REInnovationFootprint:TH_Encoder |  |  |  |  |  |  | £1.00
F1 | 500mA | REInnovationFootprint:TH_MC36188_FUSE |  | Resettable Fuse 60V | TE | RXEF050 | RS | 517-6635 | £0.26
J1 | JACK_TRS_6PINS | REInnovationFootprint:TH_3_5mm_Jack |  |  |  |  |  |  | £0.20
J2 | Arduino_Nano_Header | REInnovationFootprint:NANO_DIP_30_600 |  |  |  |  |  |  | £3.50
L1 | 22uH | REInnovationFootprint:TH_Inductor |  | >1.6A Rated 2.3A | Wurth | 744772220 | RS | 489-0043 | £0.67
LOGO1 | LOGO | CuriousElectric3:CEC_Globe_10mm_FCU
LOGO2 | LOGO | CuriousElectric3:TCEC_Words_13mm
P1 | INPUT | matts_components:SIL-2_screw_terminal_32A |  |  |  |  |  |  | £1.00
P2 | Vref? | matts_components:SIL-2_solder_connect
P3 | MicroSD | matts_components:SIL-6_large_pads_marker | http://www.gearbest.com/development-boards/pp_63013.html?currency=GBP&vip=760169 | External Micro SD slot with level shifter
P4 | A6_7 | matts_components:SIL-4_Grove_SIL |  |  |  |  |  |  | £0.40
P5 | OUTPUT | matts_components:SIL-2_screw_terminal_32A |  |  |  |  |  |  | £1.00
P6 | SERIAL | matts_components:SIL-4_Grove_SIL |  |  |  |  |  |  | £0.40
P7 | A2 | matts_components:SIL-4_Grove_SIL |  |  |  |  |  |  | £0.40
P8 | TP_Vin | matts_components:1pin_0_8mm
P9 | TP_Vout | matts_components:1pin_0_8mm
P10 | TP_FET | matts_components:1pin_0_8mm
P11 | TP_GND | matts_components:1pin_0_8mm
P12 | TP_5V | matts_components:1pin_0_8mm
P13 | TP_10V | matts_components:1pin_0_8mm
PCB1 | PCB | REInnovationFootprint:PCB_75x100mm |  |  |  |  |  |  | £3.00
Q1 | TK32A12N1 | matts_components:TO220_VERT_BUZ11_matt | http://uk.rs-online.com/web/p/mosfet-transistors/8962344/ | N Channel MOSFET 60A 120V Rds 13m | Toshiba | TK32A12N1 | RS | 896-2344 | £0.41
R1 | Rb | REInnovationFootprint:TH_Resistor_1 |  |  |  |  |  |  | £0.20
R2 | Ra | REInnovationFootprint:TH_Resistor_1 |  |  |  |  |  |  | £0.20
R3 | Rb | REInnovationFootprint:TH_Resistor_1 |  |  |  |  |  |  | £0.20
R4 | Ra | REInnovationFootprint:TH_Resistor_1 |  |  |  |  |  |  | £0.20
R5 | 4k7 | REInnovationFootprint:TH_Resistor_1 |  |  |  |  |  |  | £0.04
R6 | 5 | REInnovationFootprint:TH_Resistor_1 |  |  |  |  |  |  | £0.04
R7 | 1k | REInnovationFootprint:TH_Resistor_1 |  |  |  |  |  |  | £0.04
R8 | 100k | REInnovationFootprint:TH_Resistor_1 |  |  |  |  |  |  | £0.04
R9 | 100k | REInnovationFootprint:TH_Resistor_1 |  |  |  |  |  |  | £0.04
R10 | 100k | REInnovationFootprint:TH_Resistor_1 |  |  |  |  |  |  | £0.04
R11 | 8.2k | REInnovationFootprint:TH_Resistor_1 |  |  |  |  |  |  | £0.04
U1 | IR2117 | REInnovationFootprint:DIP-8_300_ELL | http://www.infineon.com/dgdl/ir2117.pdf?fileId=5546d462533600a4015355c84331168d | High Voltage High Side FET driver | Infineon | IR2117PBF | RS | 540-9711 | £1.76 | DigiKey
U2 | LMR16006 | REInnovationFootprint:SM_SOT23-6 | http://www.ti.com/lit/ds/symlink/lmr16006.pdf | 60V 0.6A Buck Reg | TI | LMR16006YDDCT | RS | 900-9790 | £2.50
U3 | MCP1702-50 | matts_components:TO92_MCP9701_matt | http://docs-europe.electrocomponents.com/webdocs/0a77/0900766b80a77df4.pdf | LDO 5V supply. 250mA | MicroChip | MCP1702-5002E/TO | RS | 403-856 | £0.36
VR1 | VR | REInnovationFootprint:TH_MC36188_FUSE | http://docs-europe.electrocomponents.com/webdocs/13c2/0900766b813c2445.pdf | MO Varistor 50A. 135V | EPCOS | B72214S0500K101 | RS | 289-7121 | £0.11
VR2 | VR | REInnovationFootprint:TH_MC36188_FUSE | http://docs-europe.electrocomponents.com/webdocs/13c2/0900766b813c2445.pdf | MO Varistor 50A. 135V | EPCOS | B72214S0500K101 | RS | 289-7121 | £0.11
 |  |  |  |  |  |  |  |  | £25.07

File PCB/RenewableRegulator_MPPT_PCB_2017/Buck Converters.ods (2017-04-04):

Component | Cost (ex VAT) | Supplier | Package | Details | Web | Supplier Web
LM2575HV | £4.20 | RS | TH | 75V max. 1A. Needs inductor etc. High Iq. |  | http://uk.rs-online.com/web/p/dc-dc-converters/7615508/
TPS54360B-Q1 | ? | ? | SM | 65 max. Low Iq. 3.5A. Looks good. Hard to find. | http://www.ti.com/lit/ds/symlink/tps54360b-q1.pdf
LMR16020 S | 4.18 | DigiKey | SM | 60V max. 2A out. Low Iq. Adjustable Vout. GOOD | http://www.ti.com/lit/ds/symlink/lmr16020.pdf | https://www.digikey.co.uk/product-detail/en/texas-instruments/LMR16020PDDA/296-44512-5-ND/6110577
LMR16010 S | 3.44 | DigiKey | SM | 60V max. 1A out. Low Iq. Adjustable Vout. GOOD | http://www.ti.com/lit/ds/symlink/lmr16010.pdf | https://www.digikey.co.uk/product-detail/en/texas-instruments/LMR16010PDDA/296-44511-5-ND/6110576
LMR16006XDDCT | 2.72 | DigiKey | SM | 60V max. 600mA out. Low Iq. Adjustable Vout. PERFECT | http://www.ti.com/lit/ds/symlink/lmr16006.pdf

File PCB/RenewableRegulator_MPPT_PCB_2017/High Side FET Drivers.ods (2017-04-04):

Component | Cost (ex VAT) | Supplier | Package | Details | Web | Supplier Web
HT0740 | 0.91 | Digi-Key | 8 SOIC | 400V isolated output. Uses input logic to generate voltage | http://ww1.microchip.com/downloads/en/DeviceDoc/20005628A.pdf
FAN7085_GF085 | 1.09 | Digi-Key |  |  | https://www.fairchildsemi.com/datasheets/FA/FAN7085_GF085.pdf
IRS10752LPBF | 0.65 | Digi-Key | 6 SPT-23 | 10-12V supply required. But up to 100V | http://www.infineon.com/dgdl/irs10752lpbf.pdf?fileId=5546d462533600a40153567308ca276d
IR2117 | 1.76 | RS | 8 PDIP | 10-20V supply required. UP to 600V. DIP package | http://www.infineon.com/dgdl/ir2117.pdf?fileId=5546d462533600a4015355c84331168d | http://uk.rs-online.com/web/p/mosfet-power-drivers/5409711/
IR2010 | 2.87 | RS | 14 PDIP | High and Low side. NOT OK. 10-20V supply required. UP to 200V. DIP package | http://www.infineon.com/dgdl/ir2010.pdf?fileId=5546d462533600a4015355c48f901660

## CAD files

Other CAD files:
Enclosure/Metal Box/1590BB/1590BB.dwg

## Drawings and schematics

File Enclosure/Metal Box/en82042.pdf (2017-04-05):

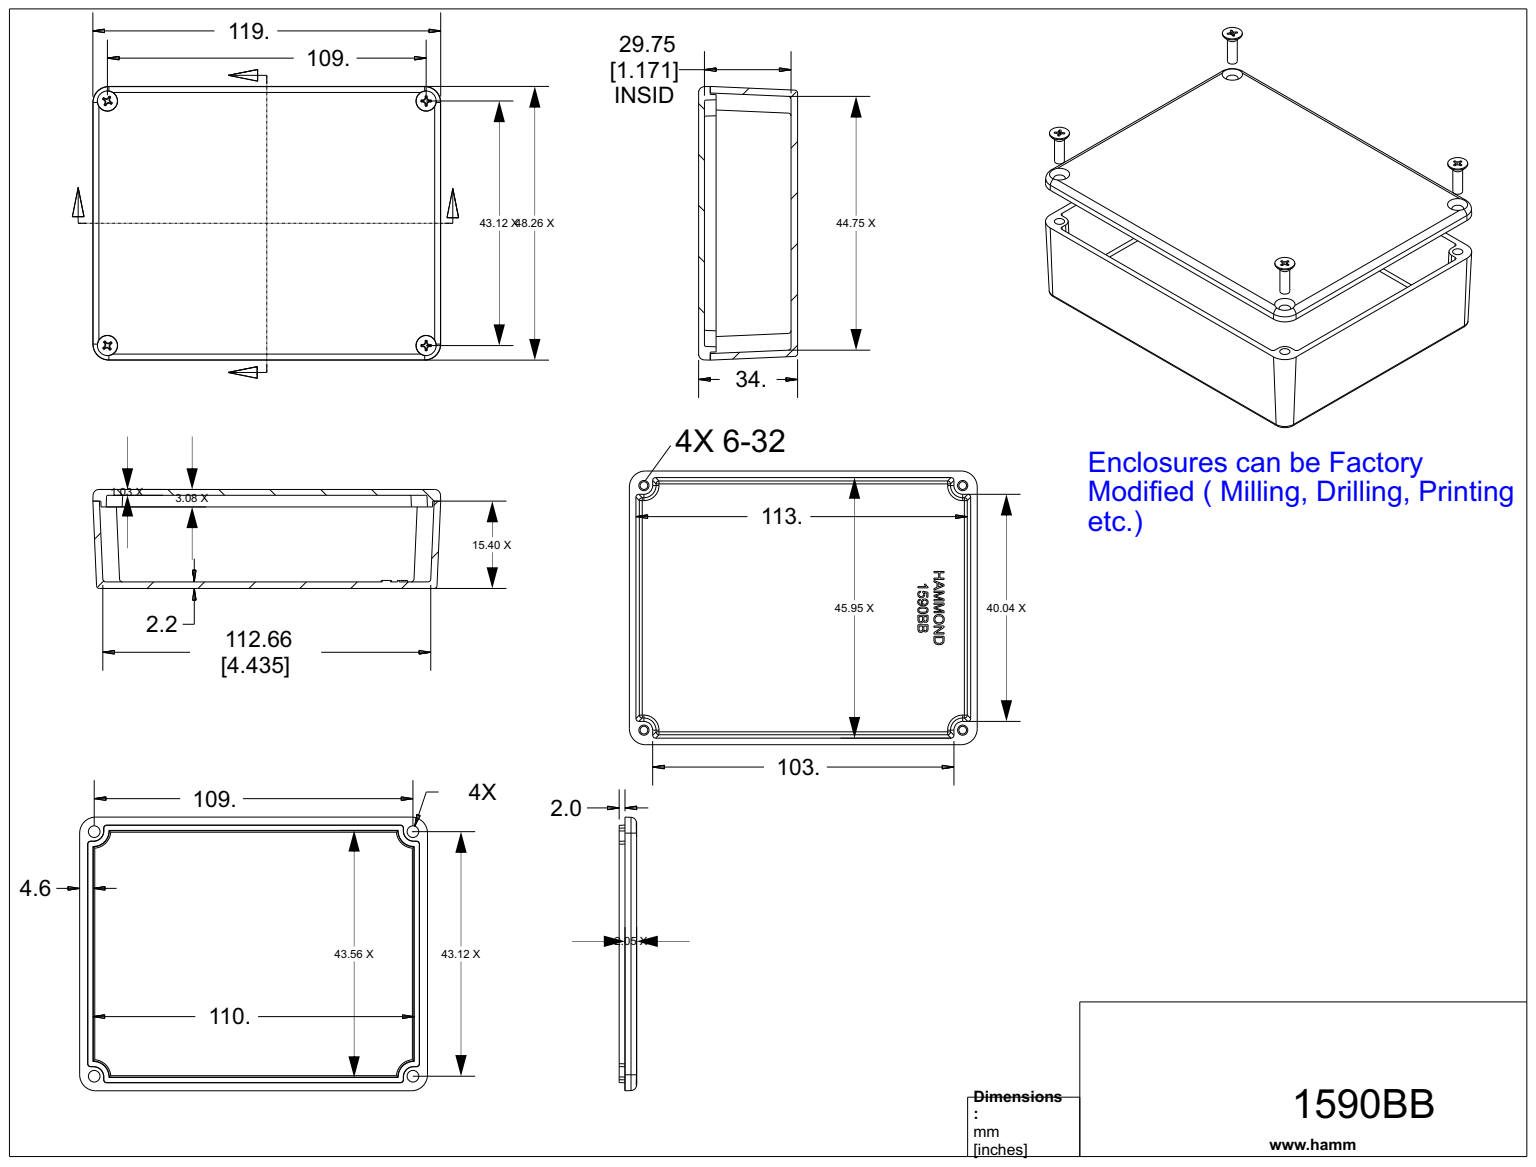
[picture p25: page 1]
Dimensions : mm; [inches]; www.hamm; Enclosures can be Factory; 29.75 [1.171] INSID

Modified ( Milling, Drilling, Printing
etc.)

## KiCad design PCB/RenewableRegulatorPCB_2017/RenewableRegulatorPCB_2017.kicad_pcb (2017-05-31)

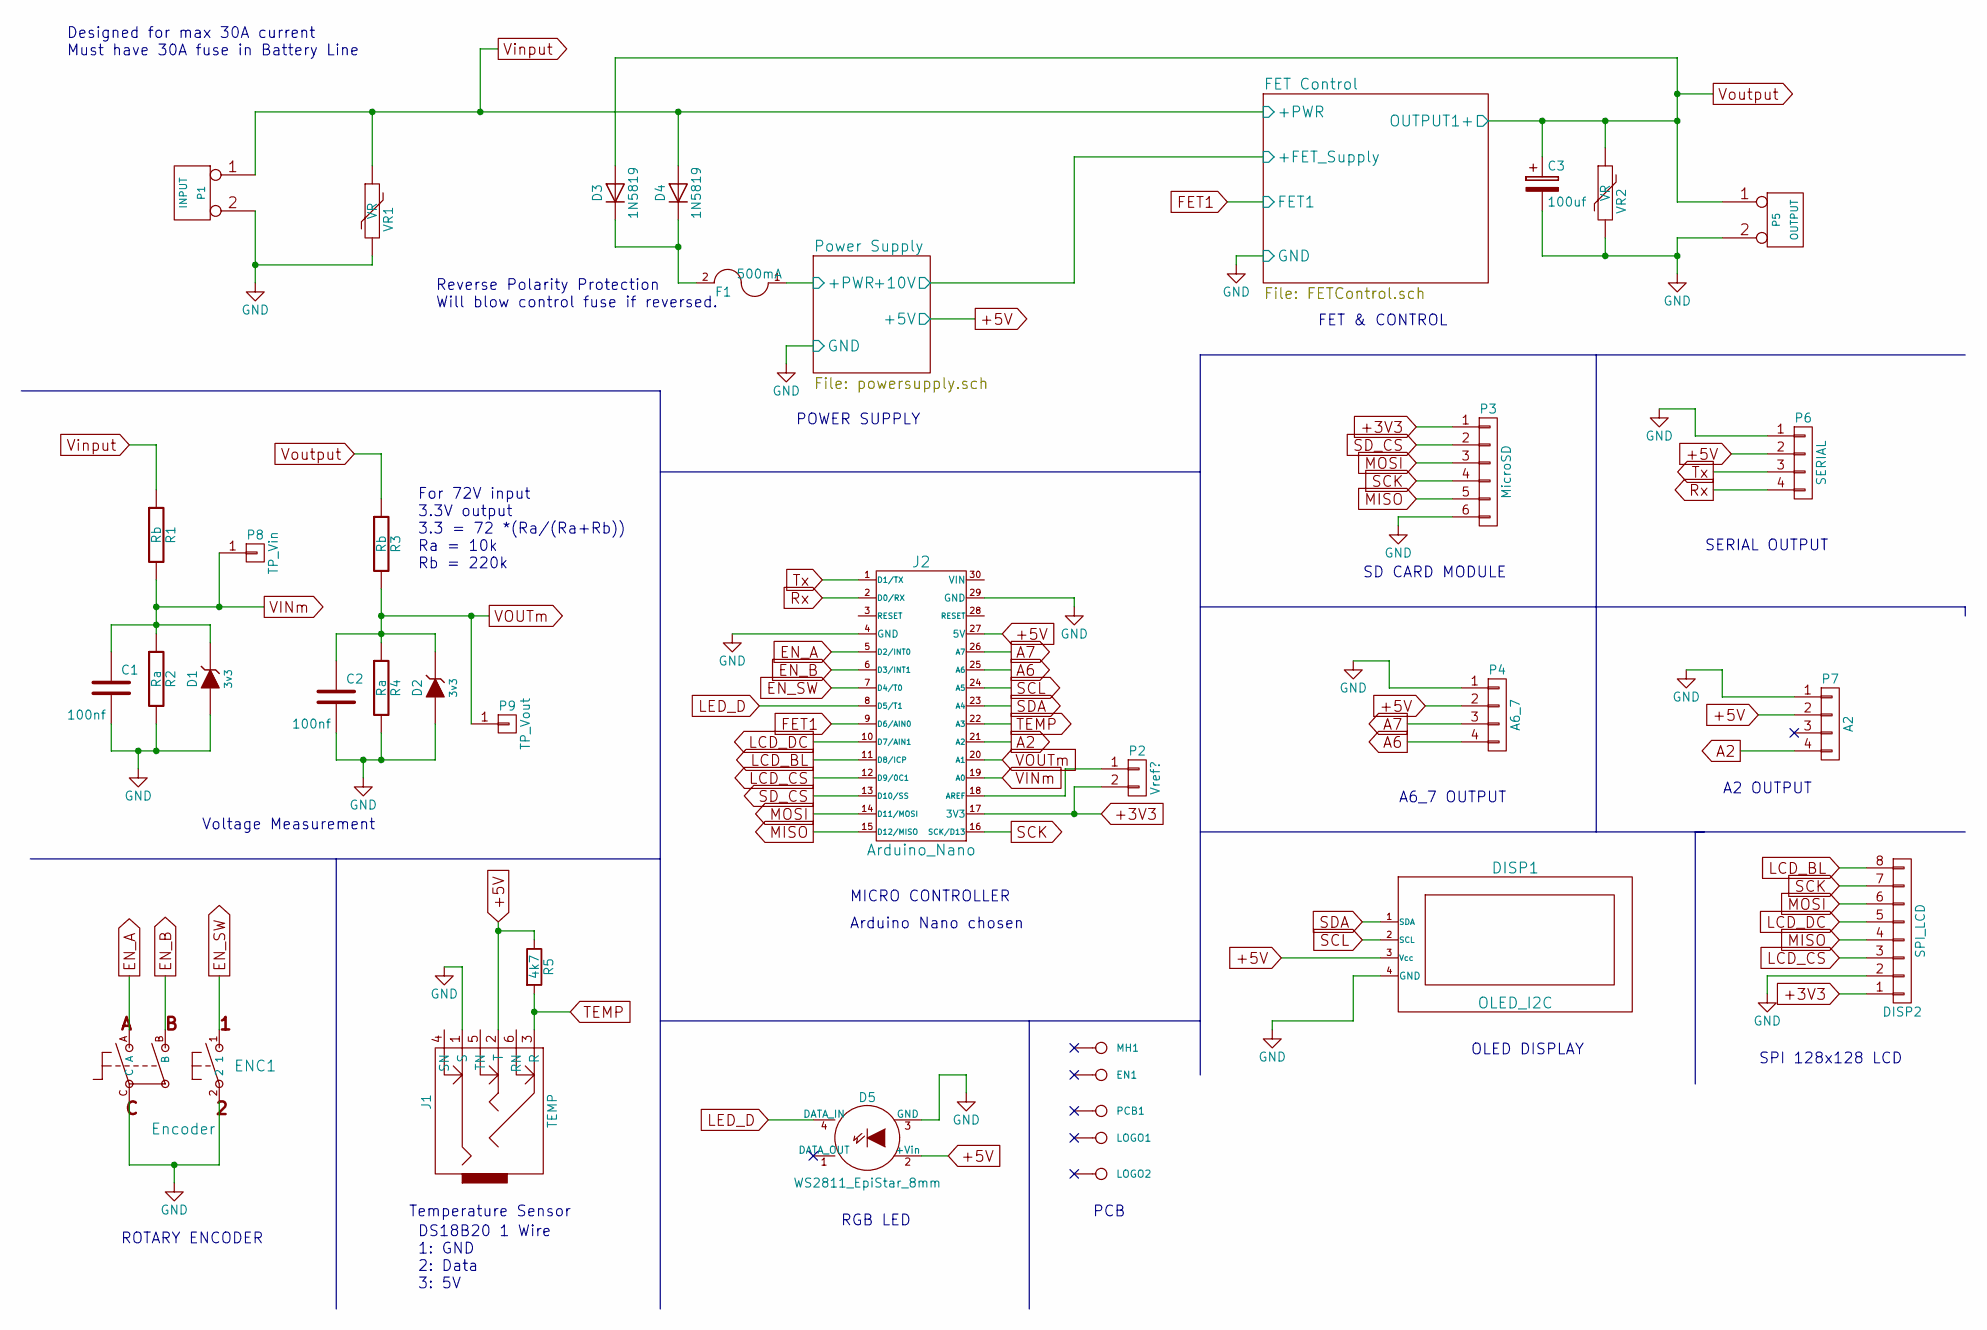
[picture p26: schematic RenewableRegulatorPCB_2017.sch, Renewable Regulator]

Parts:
C1, C2: 100nf; C1_wide_lg_pad
C3: 100uf; Capacitor_C_1V7_TH; Manufacturer Part No ECA-2AM101B
D1, D2: 3v3; TH_Diode_1
D3, D4: 1N5819; TH_Diode_1; Manufacturer Part No 1N5819
D5: WS2811_EpiStar_8mm; TH_WS2811_LED_8mm
DISP1: OLED_I2C; TH_OLED1306
DISP2: SPI_LCD; TH_LCD_SPI_128x128
EN1: PCB
ENC1: Encoder; TH_Encoder
F1: 500mA; TH_MC36188_FUSE; Manufacturer Part No RXEF050
J1: TEMP; TH_3_5mm_Jack
J2: Arduino_Nano; NANO_DIP_30_600
LOGO1: LOGO; CEC_Globe_10mm_FCU
LOGO2: LOGO; TCEC_Words_13mm
MH1: Mounting holes
P1: INPUT; Connecteurs_IO_SIL-2_screw_terminal_32A
P2: Vref?; SIL-2_solder_connect
P3: MicroSD; SIL-6_large_pads_marker
P4: A6_7; SIL-4_Grove_SIL
P5: OUTPUT; Connecteurs_IO_SIL-2_screw_terminal_32A
P6: SERIAL; SIL-4_Grove_SIL
P7: A2; SIL-4_Grove_SIL
P8: TP_Vin; 1pin_0_8mm
P9: TP_Vout; 1pin_0_8mm
PCB1: PCB; PCB_75x100mm
R1, R3: Rb; TH_Resistor_1
R2, R4: Ra; TH_Resistor_1
R5: 4k7; TH_Resistor_1
VR1, VR2: VR; TH_MC36188_FUSE; Manufacturer Part No B72214S0500K101

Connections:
+3V3: DISP2.1, J2.17 (3V3), P2.2, P3.1
+5V: D5.2 (+Vin), DISP1.3 (Vcc), J1.2 (T), J2.27 (5V), P4.2, P6.2, P7.2, R5.1; also elsewhere on the board
/Power Supply/+PWR: F1.1; also elsewhere on the board
A2: J2.21 (A2), P7.4
A6: J2.25 (A6), P4.4
A7: J2.26 (A7), P4.3
EN_A: ENC1.A, J2.5 (D2/INT0)
EN_B: ENC1.B, J2.6 (D3/INT1)
EN_SW: ENC1.1, J2.7 (D4/T0)
FET1: J2.9 (D6/AIN0); also elsewhere on the board
GND: C1.2, C2.2, C3.2, D1.1 (A), D2.1 (A), D5.3 (GND), DISP1.4 (GND), DISP2.2, ENC1.2, ENC1.C, J1.1 (S), J2.4 (GND), J2.29 (GND), P1.2, P3.6, P4.1, P5.2, P6.1, P7.1, R2.2, R4.2, VR1.2, VR2.2; also elsewhere on the board
LCD_BL: DISP2.8, J2.11 (D8/ICP)
LCD_CS: DISP2.3, J2.12 (D9/0C1)
LCD_DC: DISP2.5, J2.10 (D7/AIN1)
LED_D: D5.4 (DATA_IN), J2.8 (D5/T1)
MISO: DISP2.4, J2.15 (D12/MISO), P3.5
MOSI: DISP2.6, J2.14 (D11/MOSI), P3.3
unnamed: D3.1 (K), D4.1 (K), F1.2
unnamed: J2.18 (AREF), P2.1
Rx: J2.2 (D0/RX), P6.4
SCK: DISP2.7, J2.16 (SCK/D13), P3.4
SCL: DISP1.2 (SCL), J2.24 (A5)
SDA: DISP1.1 (SDA), J2.23 (A4)
SD_CS: J2.13 (D10/SS), P3.2
TEMP: J1.3 (R), J2.22 (A3), R5.2
Tx: J2.1 (D1/TX), P6.3
VINm: C1.1, D1.2 (K), J2.19 (A0), P8.1, R1.2, R2.1
VOUTm: C2.1, D2.2 (K), J2.20 (A1), P9.1, R3.2, R4.1
Vinput: D4.2 (A), P1.1, R1.1, VR1.1; also elsewhere on the board
Voutput: C3.1, D3.2 (A), P5.1, R3.1, VR2.1; also elsewhere on the board

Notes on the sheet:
PCB
Voltage Measurement
RGB LED
ROTARY ENCODER
OLED DISPLAY
SERIAL OUTPUT
SD CARD MODULE
FET & CONTROL
POWER SUPPLY
MICRO CONTROLLER
Designed for max 30A current Must have 30A fuse in Battery Line
Reverse Polarity Protection Will blow control fuse if reversed.
SPI 128x128 LCD
Temperature Sensor
DS18B20 1 Wire 1: GND 2: Data 3: 5V
A2 OUTPUT
A6_7 OUTPUT
For 72V input 3.3V output 3.3 = 72 *(Ra/(Ra+Rb)) Ra = 10k Rb = 220k
Arduino Nano chosen

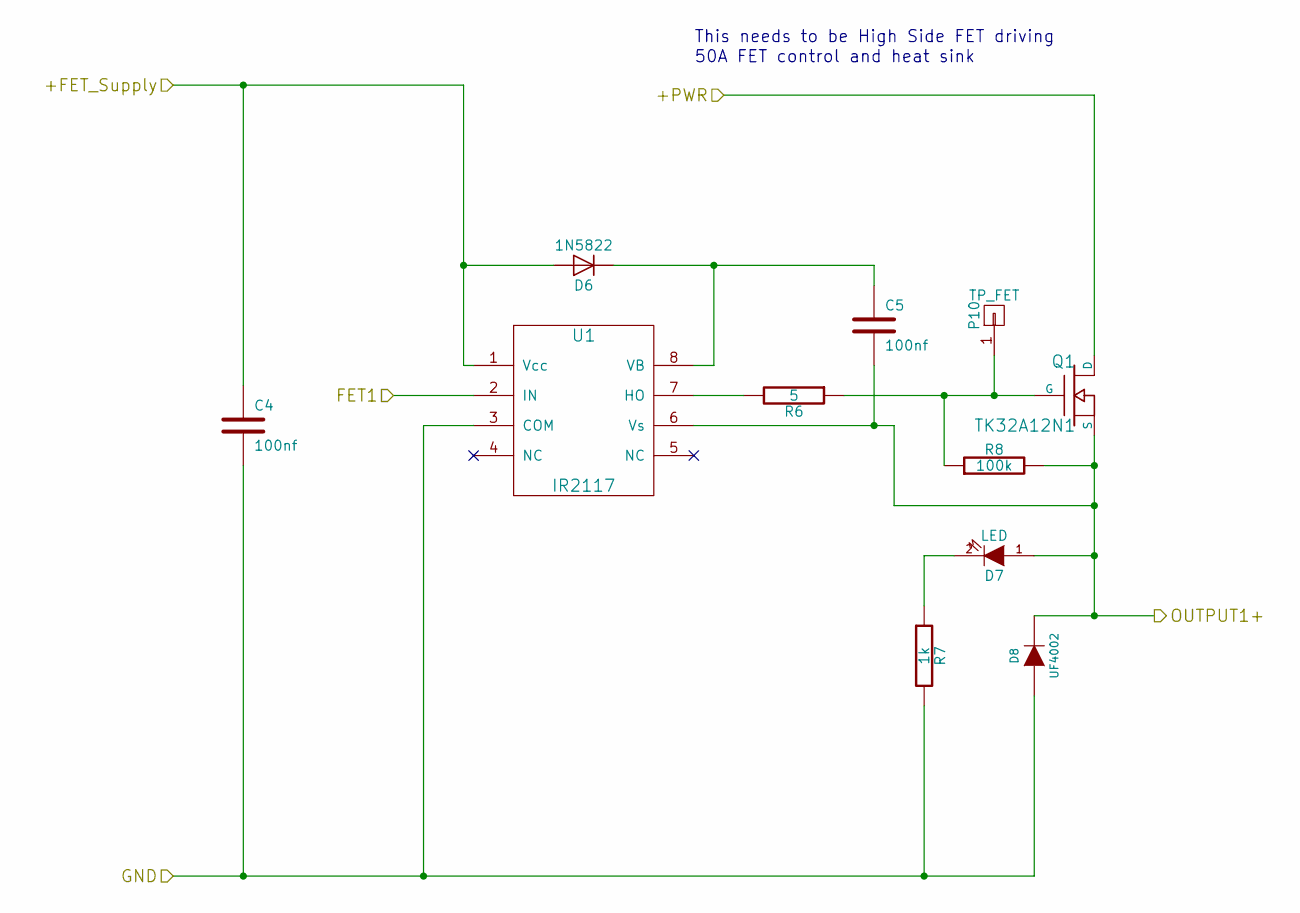
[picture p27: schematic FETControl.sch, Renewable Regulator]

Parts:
C4, C5: 100nf; C1_wide_lg_pad
D6: 1N5822; TH_Diode_1; Manufacturer Part No 1N5822
D7: LED; TH_LED-5MM_larg_pad
D8: UF4002; TH_Diode_1; Manufacturer Part No UF4002-E3
P10: TP_FET; 1pin_0_8mm
Q1: TK32A12N1; TO220_VERT_BUZ11_matt; Manufacturer Part No TK32A12N1,S4X
R6: 5; TH_Resistor_1
R7: 1k; TH_Resistor_1
R8: 100k; TH_Resistor_1
U1: IR2117; DIP-8_300_ELL; Manufacturer Part No IR2117PBF

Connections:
/Power Supply/+10V: C4.1, D6.2 (A), U1.1 (Vcc); also elsewhere on the board
FET1: U1.2 (IN); also elsewhere on the board
GND: C4.2, D8.2 (A), R7.2, U1.3 (COM); also elsewhere on the board
unnamed: C5.1, D6.1 (K), U1.8 (VB)
unnamed: D7.2 (K), R7.1
unnamed: P10.1, Q1.G, R6.1, R8.1
unnamed: R6.2, U1.7 (HO)
Vinput: Q1.D; also elsewhere on the board
Voutput: C5.2, D7.1 (A), D8.1 (K), Q1.S, R8.2, U1.6 (Vs); also elsewhere on the board

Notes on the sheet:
This needs to be High Side FET driving
50A FET control and heat sink

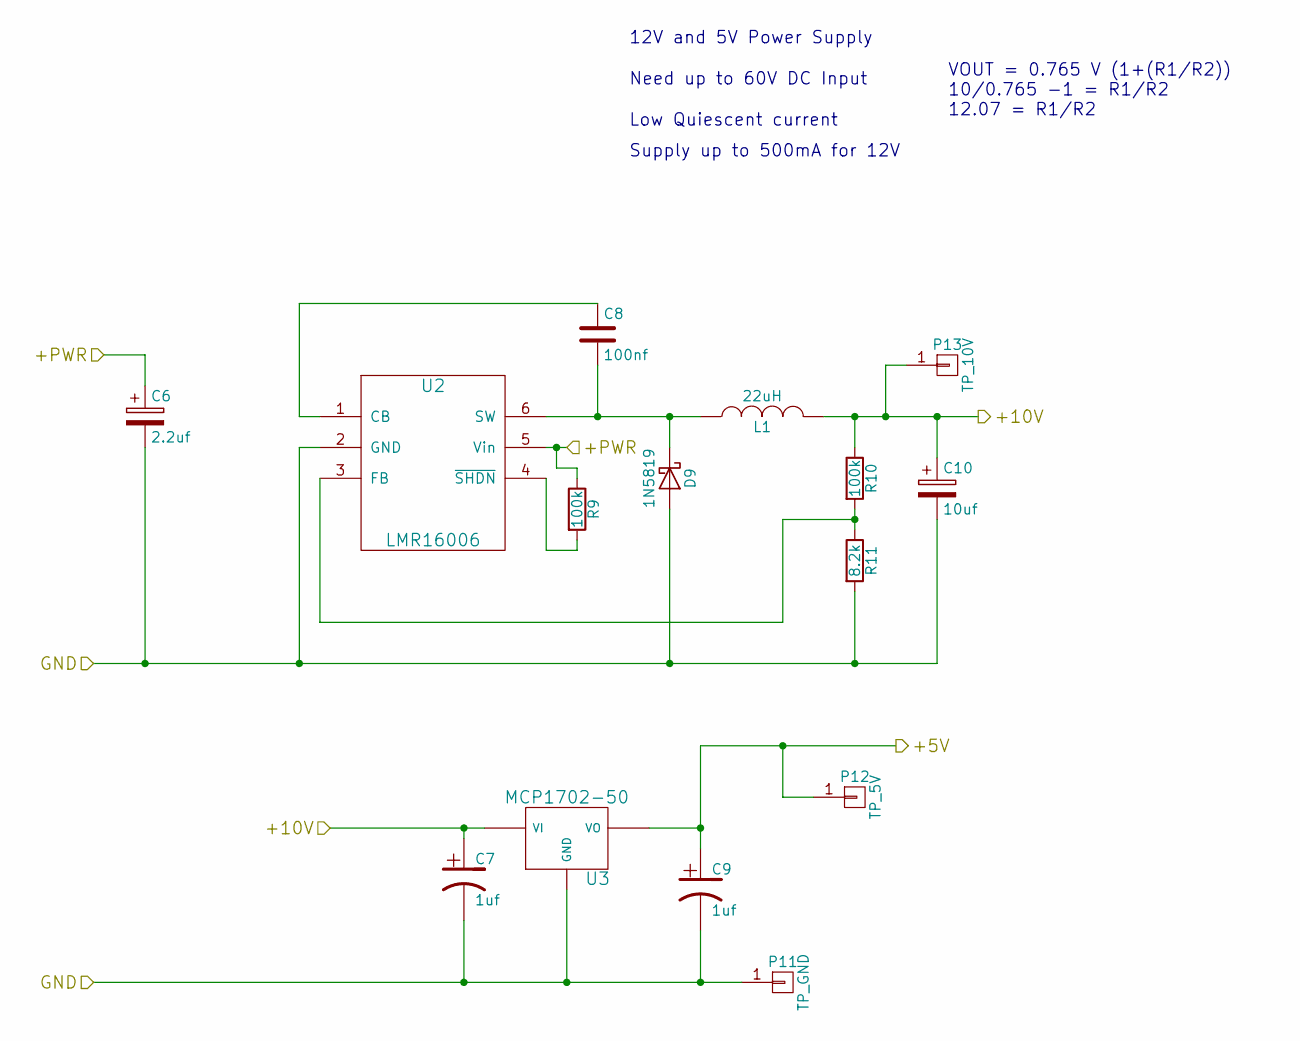
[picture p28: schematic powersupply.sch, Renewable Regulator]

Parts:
C6: 2.2uf; Capacitor_C6_1V7_TH; Manufacturer Part No RDEC72A225K3M1H03A
C7: 1uf; Capacitor_C7_1V7_TH; Manufacturer Part No RCER71H105K2M1H03A
C8: 100nf; C1_wide_lg_pad
C9: 1uf; Capacitor_C9_1V7_TH; Manufacturer Part No RCER71H105K2M1H03A
C10: 10uf; Capacitor_C10_1V7_TH; Manufacturer Part No EEUFR1H100
D9: 1N5819; TH_Diode_1; Manufacturer Part No 1N5819
L1: 22uH; TH_Inductor; Manufacturer Part No 744772220
P11: TP_GND; 1pin_0_8mm
P12: TP_5V; 1pin_0_8mm
P13: TP_10V; 1pin_0_8mm
R9, R10: 100k; TH_Resistor_1
R11: 8.2k; TH_Resistor_1
U2: LMR16006; SM_SOT23-6; Manufacturer Part No LMR16006YDDCT
U3: MCP1702-50; TO92_MCP9701_matt; Manufacturer Part No MCP1702-5002E/TO

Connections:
+5V: C9.1, P12.1, U3.VO; also elsewhere on the board
/Power Supply/+10V: C7.1, C10.1, L1.2, P13.1, R10.1, U3.VI; also elsewhere on the board
/Power Supply/+PWR: C6.1, R9.1, U2.5 (Vin); also elsewhere on the board
GND: C6.2, C7.2, C9.2, C10.2, D9.2 (A), P11.1, R11.2, U2.2 (GND), U3.GND; also elsewhere on the board
unnamed: C8.1, U2.1 (CB)
unnamed: C8.2, D9.1 (K), L1.1, U2.6 (SW)
unnamed: R9.2, U2.4 (~SHDN)
unnamed: R10.2, R11.1, U2.3 (FB)

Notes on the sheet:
12V and 5V Power Supply
Need up to 60V DC Input
Low Quiescent current
Supply up to 500mA for 12V
VOUT = 0.765 V (1+(R1/R2)) 10/0.765 -1 = R1/R2 12.07 = R1/R2

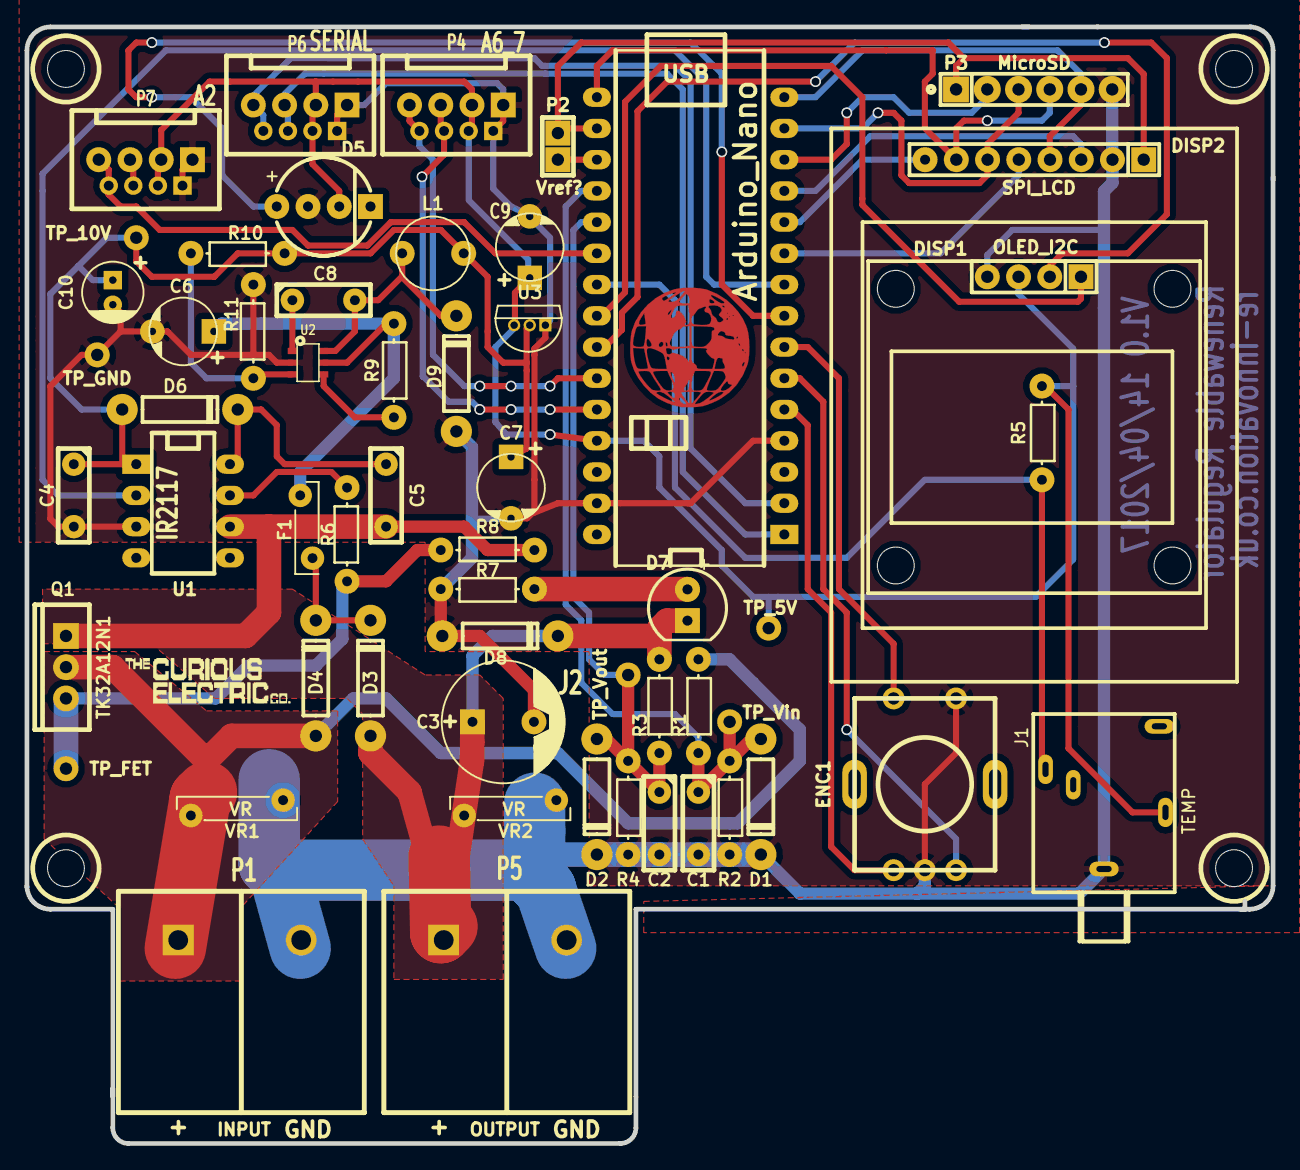
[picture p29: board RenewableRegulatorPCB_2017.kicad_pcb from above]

Board: 2 copper layers, 101.3 x 90.8 mm, 62 parts (0 on the bottom side), 39 nets.

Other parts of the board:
MH1#2, MH1#3, MH1#4: CONN_1; 3mm_hole

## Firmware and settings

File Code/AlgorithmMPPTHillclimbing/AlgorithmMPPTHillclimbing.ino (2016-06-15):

#include <LCD5110_Graph.h>

#define pwmChange 1
float constantVoltage, constantCurrent;
const int analogInPinVoltage = A5;
const int analogInPinCurrent = A4;
float maxControllerVoltage = 30;
unsigned int R1 = 10;
unsigned int R2 = 47;
float Vin;
float current;
int voltageValue;
int currentValue;
float newPower, oldPower;
int pwmValue;
LCD5110 myGLCD(12, 11, 10, 8, 9);
extern unsigned char SmallFont[];
extern unsigned char TinyFont[];
extern unsigned char MediumNumbers[];
int pwmScan=0;
int timer1_counter;
bool change = HIGH;
float pwmVariation;
float averagePower = 0;

void setup() {
  // put your setup code here, to run once:
  
  pwmVariation = pwmChange;    // Give the value of pwmChange to pwmVariation
  Serial.begin(115200);

  constantCurrent = (5000.0 / 1023.0);
  constantVoltage = (maxControllerVoltage / 1024.0) * ((R2 + R1) / R2);
  
  pinMode(5, OUTPUT);           // Select pinMode
  pinMode(13, OUTPUT);          // Select pinMode
  initLCD(1000);                 //Initialise Lcd
  scan();                        //Call the function which will find the mppt at the startup
  
   // initialize timer1 
  noInterrupts();           // disable all interrupts
  TCCR1A = 0;
  TCCR1B = 0;

  // Set timer1_counter to the correct value for our interrupt interval
  //timer1_counter = 64911;   // preload timer 65536-16MHz/256/100Hz
 //timer1_counter = 64286;   // preload timer 65536-16MHz/256/50Hz
 timer1_counter = 34286;   // preload timer 65536-16MHz/256/2Hz
  
  TCNT1 = timer1_counter;   // preload timer
  TCCR1B |= (1 << CS12);    // 256 prescaler 
  TIMSK1 |= (1 << TOIE1);   // enable timer overflow interrupt
  interrupts();             // enable all interrupts


}


ISR(TIMER1_OVF_vect)        // interrupt service routine 
{
  TCNT1 = timer1_counter;

  // Write to the PWM to change the power level
  analogWrite(5, (pwmValue)); // Do we do this here?

  // Measure the new power. 
  getMeasure();                       //measure power
  
  newPower = averagePower;
  
 //////////////////////////////////////////////////////////////////////
 ////////// Adapt Speed of tracking/////////////////////////////////.
 /////////////////////////////////////////////////////////////////
// pwmVariation = abs(newPower - oldPower);
// //Serial.println((int)pwmVariation); 
// // Covert float to int
// if (pwmVariation <=1)
// {
//  pwmVariation =  1;
// }
 pwmVariation =  1;
 //////////////////////////////////////////////////////////////////
 /////////////////////////////////////////////////////////////////

  
  if (change == HIGH )                                            //algorithm of the mppt
  {
    if (newPower >= oldPower)
    {
      pwmValue = pwmValue + (int)pwmVariation;
      change = HIGH;
    }
    else if (newPower < oldPower)
    {
      pwmValue = pwmValue - (int)pwmVariation;
      change = LOW;
    }
  }
  else if (change == LOW)
  {
    if(newPower >= oldPower)
    {
      pwmValue = pwmValue - (int)pwmVariation;
      change = LOW;
    }
    else if (newPower < oldPower)
    {
      pwmValue = pwmValue + (int)pwmVariation;
      change = HIGH;
    }
  }
  Serial.print("Gradient:");
  Serial.println(change);
  

if (pwmValue >= 255)                          //Prevent the pwmValue to go higher than its limit
{
  pwmValue = 255;
}
else if (pwmValue <= 0)                         //Prevent the pwmValue to go lower than its limit
{
  pwmValue = 0;
  
}
 Serial.print(" nPow : ");                       //display serial information
 Serial.print(newPower); 
 Serial.print(" and ");
 Serial.print(" oPow : ");
 Serial.print(oldPower);
 Serial.print(" PWM = ");
 Serial.println(pwmValue);
// Serial.println();
// Serial.print(current);
// Serial.println();

 oldPower = newPower;                       // save the newPower as the oldPower

 displayLCD();                              // Display the information on the LCD
 
}

void loop() {
  
  
//nothing//

}

void getMeasure (void)
{ 
  digitalWrite(7,HIGH);
  float averageVoltage = 0;
  float averageCurrent = 0;

  // Taking V and I measurments
    
  for(char i = 0; i < 100 ; i++)
  {
   averageVoltage = averageVoltage + getVin();
   averageCurrent = averageCurrent + getAmp();
   averagePower = averagePower + (getVin()*getAmp());
  }

  averageVoltage = averageVoltage/100;
  averageCurrent = averageCurrent /100;
  averagePower = averagePower/100;
  
  //current = ((averageCurrent - 2493) / 183);
  Serial.print("Power:");
  Serial.println(averagePower);
  digitalWrite(7,LOW);  
}
float getVin(void)                                              // Get Vin value and store it in the global declaration Vin
{ 
  Vin = (analogRead(A5) * constantVoltage);
  return (Vin);
}

float getAmp()                  // gets the current in Amp
{
  
  current= ((constantCurrent * analogRead(A4))-2493)/183; //this is
  return (current);
}

float powerCalculation(void)      // Calculation of the power
{ float Power;
  Power = current * Vin;
  return (Power);
}



void initLCD( int tempo )       //Init the lcd and display Matthew information
{
  myGLCD.InitLCD();
  digitalWrite(13, HIGH);
  myGLCD.setFont(SmallFont);

  myGLCD.clrScr();
  myGLCD.print("SerieRegulator", CENTER, 0);
  myGLCD.print("RE-INNOVATION", CENTER, 20);
  myGLCD.setFont(TinyFont);
  myGLCD.print("(C)2016 by", CENTER, 36);
  myGLCD.print("Matthew Little", CENTER, 42);
  myGLCD.update();

  delay(tempo);
  myGLCD.clrScr();
  myGLCD.update();



}


void displayLCD(void)             // display the current, voltage , power and pwm information on the LCD
{
  myGLCD.clrScr();

  myGLCD.setFont(SmallFont);
  myGLCD.print("VOLTAGE", LEFT, 0);
  myGLCD.printNumF(Vin, 1, RIGHT, 0);

  myGLCD.print("CURRENT", LEFT, 12);
  myGLCD.printNumF(current, 1, RIGHT, 12);

  myGLCD.print("POWER", LEFT, 22);
  myGLCD.printNumF(newPower, 1, RIGHT, 22);

  myGLCD.print("PWM", LEFT, 32);
  myGLCD.printNumI(pwmValue, RIGHT, 32);

  myGLCD.update();


}

void scan(void)                                     // Used one time at the startup of the program. It will place the pwmValue at the mppt.
{ float Power = 0;
  float olderPower = 0;

  myGLCD.setFont(SmallFont);
  
  for (pwmValue = 0 ; pwmValue < 254; pwmValue ++)
  {
    analogWrite(5, pwmValue);
    //voltageValue = analogRead(analogInPinVoltage);
    //currentValue = analogRead(analogInPinCurrent);
    getMeasure();
    Power = powerCalculation();
    //Serial.println(Power);
    if ((Power - olderPower ) >= 0)
    {
      olderPower = Power;
      pwmScan = pwmValue;
    }
    else
    {
    }


  }
  pwmValue = pwmScan;



}

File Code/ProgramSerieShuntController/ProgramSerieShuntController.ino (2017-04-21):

/*#include <Adafruit_NeoPixel.h>
#ifdef __AVR__
  #include <avr/power.h>
#endif*/

/* Encoder Library, for measuring quadrature encoded signals
 * http://www.pjrc.com/teensy/td_libs_Encoder.html
 * Copyright (c) 2011,2013 PJRC.COM, LLC - Paul Stoffregen <paul@pjrc.com>
 *
 * Version 1.2 - fix -2 bug in C-only code
 * Version 1.1 - expand to support boards with up to 60 interrupts
 * Version 1.0 - initial release
 */

/*******Watchdog timer by http://donalmorrissey.blogspot.co.uk/2010/04/sleeping-arduino-part-5-wake-up-via.html *********/

/*******LCD5110_Library to control the lcd http://www.rinkydinkelectronics.com/library.php?id=48 *******/

/*******U8glib.h C++ Interface Universal 8bit Graphics Library Copyright (c) 2011, olikraus@gmail.com***/

/*******DECLARATIONS*******/
/*#define LED_PIN            7

Adafruit_NeoPixel LED_RGB = Adafruit_NeoPixel(1, LED_PIN, NEO_GRB + NEO_KHZ800);*/

#include <SerieShuntController.h>
#include <avr/sleep.h>
#include <avr/power.h>
#include <avr/wdt.h>
#include <avr/pgmspace.h>

OLED_Display disp;
Encoder_control enco;
Value val;
Control contr;


volatile int f_wdt=1;                                             // Sleep arduino

//////////////////////////////////////////////////////////////////////////////////////////////////////////////////////////////////////////////
///////////SETUP//////////////////////////////////////////////////////////////////////////////////////////////////////////////////////////////
//////////////////////////////////////////////////////////////////////////////////////////////////////////////////////////////////////////////

void setup() {
   
  // put your setup code here, to run once:
  // initialize serial:
  Serial.begin(9600);
          
  disp.initOLED();                               // Setup the WDT
  
  MCUSR &= ~(1<<WDRF);                      // Clear the reset flag  
  WDTCSR |= (1<<WDCE) | (1<<WDE);           // In order to change WDE or the prescaler, we need to set WDCE (This will allow updates for 4 clock cycles).
  WDTCSR = 1<<WDP0 | 1<<WDP1;               // Set new watchdog timeout prescaler value (0.125 seconds)
  WDTCSR |= _BV(WDIE);                      // Enable the WD interrupt (note no reset)
  

  delay(100);                               //Allow for serial print to complete.
}




////////////////////////////////////////////////////////////////////////////////////////////////////////////////////////////////////////////
////////////LOOP////////////////////////////////////////////////////////////////////////////////////////////////////////////////////////////
////////////////////////////////////////////////////////////////////////////////////////////////////////////////////////////////////////////

void loop() {
  // put your main code here, to run repeatedly:
  char i = 0; 
  static float setpointHigh;                          // Set setpointHigh Caution the battery may go beyond the overcharge
  static float setpointLow;                           // Set setpointLow
  static float VinMax;                                // Maximum Input Voltage Default = 4
  static unsigned int R1;                             // Bottom resistance Kohm Default = 10
  static unsigned int R2 ;                            // top resistance Kohm     Default = 100 
  static float maxControllerVoltage ;                 // the arduino Uno boardcard cant excess 5 volt   default = 5v
  static float hysteresis ;                           // Value of the hysteresis
  static unsigned int times;    
  static char first_time = 1;
  static char selection = 0;
  static float Vin;
  static int sensorValue = 0; 
  static long posit = 0;
  static long newPos = 0;
  static int limitSetpointHighInAnalog;               // Limit of the setpointhigh in analog value
  static int limitSetpointLowInAnalog;                // Limit of the setpointlow in analog value
  static unsigned char cpt =0;
  static unsigned char curveCpt = 0;
  static unsigned char curveTab[120] ;
  
  if (first_time == 1)
  {
    val.initEEPROMValue(VinMax, maxControllerVoltage, R1, R2, hysteresis, times);                        // initialization of VinMax, maxControllerVoltage, R1, R2, hysteresis and times with the last values stored in the EEPROM
    val.updateValue(setpointHigh, setpointLow, VinMax, hysteresis);
    for (i = 0; i<120; i++)
    {
      curveTab[i]= 0;
    }
    first_time = 0;  
  }
  
  if(f_wdt == 1)
  {
    selection = enco.configureSelection(sensorValue, setpointHigh, setpointLow, maxControllerVoltage, newPos, posit, limitSetpointHighInAnalog, limitSetpointLowInAnalog);           // Changes the value of "selection" depending on the position of the encoder
    contr.seriesRegulator(sensorValue, maxControllerVoltage, selection, setpointHigh, setpointLow, Vin, limitSetpointHighInAnalog, limitSetpointLowInAnalog);              // Write 0 in the parenthesis for no PWM or 1 for the PWM //default selection
    disp.displayOLED(selection, sensorValue, setpointHigh, setpointLow, Vin, VinMax, maxControllerVoltage, times, limitSetpointHighInAnalog, limitSetpointLowInAnalog, cpt, curveTab, curveCpt);         // Default selection
    disp.enableMenu(enco.testButtonC(), VinMax, maxControllerVoltage, R1, R2, hysteresis, times, setpointHigh, setpointLow, newPos, posit);      // Displays the menu if you press the rotary encoder // You can change Vlim, Vmax, R1, R2, hysteresis, times and decide if you the arduino to sleep depending on the position of the encoder
    f_wdt = 0;

    contr.enterSleepArduino();            // Re-enter sleep mode
  }
  else
  {
    /* Do nothing. */
  }
}

ISR(WDT_vect)                             //Watchdog Interrupt Service. This is executed when watchdog timed out
{
  if(f_wdt == 0)
  {
    f_wdt=1; 
  }
  else
  {
             //Serial.println("WDT Overrun!!!");
  }
}

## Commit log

2017-04-03 Updated files for Yoan
    Added PCB. Removed .word report from Arnaud
    [RenewableRegulatorPCB_2017.brd, RenewableRegulatorPCB_2017.kicad_pcb, RenewableRegulatorPCB_2017.sch]
2017-04-04 Code with rotary encoder
2017-04-04 Updated PCB
    First version of schematic. Needs review
    [Buck Converters.ods, FETControl.sch, High Side FET Drivers.ods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]
2017-04-05 Moved code into new file structure
    [FETControl.sch, RenewableRegulatorPCB_2017.sch, _saved_FETControl.sch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]
2017-04-05 Update of metal box
    [1590BB.dwg]
2017-04-05 Large update of PCB design
    [FETControl.sch, RenewableRegulatorPCB_2017.csv, RenewableRegulatorPCB_2017.kicad_pcb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]
2017-04-07 First Version of PCB
    [FETControl.sch, RenewableRegulatorPCB_2017.kicad_pcb, RenewableRegulatorPCB_2017.sch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]
2017-04-10 Added MH and footprints
    [FETControl.sch, RenewableRegulatorPCB_2017.sch, powersupply.sch]
2017-04-11 Third Version of PCB
    [FETControl.sch, RenewableRegulatorPCB_2017.kicad_pcb, RenewableRegulatorPCB_2017.sch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]
2017-04-12 BOM uploaded
2017-04-14 Updated PCB and schematic
    WS2811 LED swapped around Vcc and GND
    OLED swapped around for front mounting
    Tracks cleaned up
    [FETControl.sch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]
2017-04-20 Minor PCb changes. Fit to 100mm x 100mm
    [RenewableRegulatorPCB_2017-B.Mask.gbs, RenewableRegulatorPCB_2017-B.SilkS.gbo, RenewableRegulatorPCB_2017-Back.gbl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]
2017-04-20 BOM updated
    [RenewableRegulatorPCB_2017.csv]
2017-04-26 MPPT PCB schematic
    [BUCK converter.sch, Buck Converters.ods, FETControl.sch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]
2017-05-05 First version MPPT PCB
    [BUCK converter.sch, RenewableRegulator_MPPT_PCB_2017.kicad_pcb, RenewableRegulator_MPPT_PCB_2017.sch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]
2017-05-05 Regulator PCB changes
    [RenewableRegulatorPCB_2017.csv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]
2017-05-08 Updated PCB of MPPT
    [RenewableRegulator_MPPT_PCB_2017.kicad_pcb, _saved_RenewableRegulator_MPPT_PCB_2017.sch]
2017-05-08 Flow diagram for the series shunt controller
2017-05-19 Updated MPPT PCB
    [RenewableRegulator_MPPT_PCB_2017.kicad_pcb, RenewableRegulator_MPPT_PCB_2017.sch, currentMeasurment.sch]
2017-05-31 Last version of regulator PCB
    [FETControl.sch, RenewableRegulatorPCB_2017.kicad_pcb, RenewableRegulatorPCB_2017.sch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]
